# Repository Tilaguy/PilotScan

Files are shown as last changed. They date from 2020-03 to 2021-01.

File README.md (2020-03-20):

## PILOT SCAN
---
### 1. Descripción

En este repositorio se encuentran alojados los algoritmos necesarios para elaborar una interfaz de comunicación codificada con capacidad de detección de errores, durante el proceso de envío. Esta interfaz hace parte del sistema titulado **PilotScan\***, el cual consta de un sistema central de procesamiento y un sistema de respaldo que monitora de forma continua, el estado del sistema tanto a nivel hardware como software, además tiene la capacidad de realizar acciones indicadas por sistema central, sobre los diferentes módulos que conforman el sistema.

Para el sistema central de procesamiento, se usa una **Intel®️ NUC Board** con Linux 16.04 server. Para el sistema de respaldo se emplea un **dsPIC 30F4011**, el cual conecta diferentes sensores analógicos y digitales, tiene la capacidad de habilitar y deshabilitar fuentes reguladas de *12 V* y *24 V*, además de emitir mensajes al usuario a través de una bocina y leds RGB programables.

**\*** La información detallada del sistema se encuentra alojada en el repositorio: \ link \

---
## 2. Repository organization
Este repositorio se encuentra organizado de la siguiente forma:

### 2.1. PIC
* *Timer.c*:  Este archivo genera un reloj a frecuencia constante en un microcontrolador **PIC 16f506**, el cual sirve como base de tiempo para garantizar que el sistema de firmware está en funcionamiento.
### 2.2. Python
Estos archivos son nodos para ROS, los cuales interactúan entre sí por medio de tópicos para el monitoreo, procesamiento y acción sobre los diferentes módulos que conforman el sistema **PilotScan**.

* *Firmware.py*:  Nodo encargado de la recepción y transmisión serial con el sistema de respaldo.

* *Monitoring.py*:  Nodo encargado del procesamiento, codificación y decodificación de la información mediante protocolos diseñados para cada caso específico.

* *Resources.py*:  Nodo que lee la información del estado del sistema y la publica por medio de tópicos separados como el estado de memoria, la temperatura de los núcleos y entre otros.

### 2.3. dsPIC
#### 2.3.1. Include

* *ports.h*:  Librería para hacer asignaciones de pines según su uso y declaración de variables globales.

* *NOTAS.C*:  Librería para definir el tiempo de una nota usada por el Buzzer en el sistema.

* *TONOS.C*:  Librería donde se definen las notas musicales separado por octavas en 4 grupos de frecuencias diferentes.

* *SerialProtocol.h*:  Librería encargada de la codificación y decodificación de la información mediante protocolos diseñados para cada caso específico.

* *Hadware_actions.h*:  Librería usada para generar acciones o notificaciones del estado del sistema mediante el buzzer o los LEDs RGB.

* *Nuc_interface.h*:  Librería usada para encender y apagar el sistema de cómputo central.

* *I2C_DIR*:  Libreria que contiene las definiciones de direcciones I2C para la comunicación con algunos sensores, las funciones correspondientes para establecer dicha comunicación.

#### 2.3.2. Main
En el archivo main.c se hace uso de las librerías mencionadas anteriormente, se realiza la configuración de los diferentes periféricos de microcontrolador como modulo ADC, I2C, RS232, entre otros. Adicionalmente, se realiza la configuración y activación de interrupciones.

---

## 3. Protocolo de comunicación serial **computador-dsPIC**
El protocolo que se usa para la comunicación entre el microcontrolador y el computador genera un número que codifica la información en hexadecimal, esta codificación depende de quién es emisor del mensaje, esta codificación se explica más detalladamente a continuación. Además, el protocolo cuenta con un Byte de inicio (*'$'*) que indica el comienzo del mensaje y un salto de línea (*'\n'*) que informa el final. En cualquier caso, si los Bytes de información toman los valores de 0, significa un error en la codificación.

### 3.1. Protocolo de envió desde la Intel® NUC Board
Este protocolo se construye a partir de una tabla de valores constantes, los cuales indican el estado del sistema en diferentes ámbitos tales como: monitoreo y control de las fuentes, la comunicación de problemas de ejecución y otros requerimientos necesarios para el correcto funcionamiento del sistema. Dicho protocolo consta de dos Byte, los cuales codifican la información.

El primer Byte (**data1**) indica el origen de la información (VN-300, LiDAR, estado del sistema, etc.) de la cual se está dando a conocer su estado. El segundo Byte (**data2**) informa el estado y da idea de cómo debe proceder el microcontrolador. Los dos Bytes restantes corresponden al checksum, quien funciona como sistema de detección de errores en el proceso de comunicación, pues dichos Bytes deben corresponden a la suma de los dos primeros (**dato1+dato2**).

Cada mensaje es interpretado por el microcontrolador quien efectúa algún tipo de acción, ya sea realizando un encendido o apagado de algún elemento, activando alertas auditivas o alertas visuales a través de leds RGB.

* **P. ej.** Si la *temperatura media de los núcleos del sistema de cómputo* esta entre 35 °C y 40 °C, en microcontrolador debe *encender los ventiladores* en cierta forma particular.
  * Mensaje enviado:
  ~~~
  data1 =      0x4
  data2 =      0xE
  checksum =   0x12
  mensaje =    '$19986\n'
  ~~~
  * Acción tomada por el microcontrolador:
  ~~~
  - Encendido de ventilador ( PWM ~ 60% )
  - LED RGB 4 ([R,G,B] = [25,128,0])
  ~~~
#### Tabla 3.1.1. Mensajes del sistema.

data 1 | data 2 | message | meaning
-- | -- | -- | -- 
0 | 0 |         |Reserve
0 | 1 | sys-on_24 |	Turn-on source 24V
0 | 2 | sys-off_12 |Turn-off source 12V
0 | 3 | sys-off_24 |Turn-off source 24V
0 | 4 | sys-mem_E |	Memory problem
0 | 5 | sys-on_m8 |	Turn LiDAR on
0 | 6 | sys-on_tty |Turn all tty ports on
0 | 7 |
0 | 8 |
0 | 9 |
0 | A |
0 | B |
0 | C |
0 | D |
0 | E |
0 | F |

#### Tabla 3.1.2. Mensajes del estado del VN300.
data 1 | data 2 | message | meaning | R | G | B |LED
-- | -- | -- | -- | -- | -- | -- |--
1 | 0 |         |Reserve|0|0|0|L1
1 | 1 | VN300-NC |	VN300 No Connected|240|0|0|L1
1 | 2 | VN300-Start |VN 300 Starting|240|128|0|L1
1 | 3 | VN300-<25 | VN300 <25%|50|0|240|L1
1 | 4 | VN300-<50 |25% < VN300 <50%|50|80|160|L1
1 | 5 | VN300-<75 |	50% < VN300 <75|50|160|80|L1
1 | 6 | VN300->75 |VN300 >75%|50|240|0|L1
1 | 7 |VN300-Work | VN300 Working|0|240|0|L1
1 | 8 |
1 | 9 |
1 | A |
1 | B |
1 | C |
1 | D |
1 | E |
1 | F |

#### Tabla 3.1.3. Mensajes del estado del LiDAR M8.
data 1 | data 2 | message | meaning | R | G | B |LED
-- | -- | -- | -- | -- | -- | -- | --
2 | 0 |         |Reserve|0|0|0|L2
2 | 1 | M8-NC |	M8 No Ping|240	|0|0|L2
2 | 2 | M8-Start |M8 Starting|240|128|0|L2
2 | 3 |
2 | 4 |
2 | 5 |
2 | 6 |
2 | 7 |M8-Work | M8 Working|0|240|0 |L2
2 | 8 |
2 | 9 |
2 | A |
2 | B |
2 | C |
2 | D |
2 | E |
2 | F |
#### Tabla 3.1.4. Mensajes del estado de la cámara.
data 1 | data 2 | message | meaning
-- | -- | -- | --
3 | 0 |         |Reserve
3 | 1 | CAM-NC | CAM No Connected
3 | 2 | CAM-Start |CAM Starting
3 | 3 |  |
3 | 4 |  |
3 | 5 |  |
3 | 6 |  |
3 | 7 |CAM-Work | CAM Working
3 | 8 |
3 | 9 |
3 | A |
3 | B |
3 | C |
3 | D |
3 | E |
3 | F |
#### Tabla 3.1.5. Mensajes del control Fuzzy para temperatura.
data 1 | data 2 | message | meaning | R | G | B|LED
-- | -- | -- | -- | -- | -- | -- |--
3 | 0 |  |Reserve|0|0|0|L4
3 | 1 |   
3 | 2 |  
3 | 3 |  
3 | 4 |  
3 | 5 |  
3 | 6 |  
3 | 7 |   
3 | 8 |
3 | 9 |
3 | A |
3 | B |
3 | C |FUZZ-T1|>25°|13	|0|	125|L4
3 | D |FUZZ-T2|>30°|113|	0|	125|L4
3 | E |FUZZ-T3|>35°|255|	128|	0|L4
3 | F |FUZZ-T4|>40°|250|0|	0|L4
#### Tabla 3.1.6. Mensajes de error de memoria.
data 1 | data 2 | message | meaning | R | G | B |LED
-- | -- | -- | -- | -- | -- | -- | --
A | 0 |  |Reserve|0|0|0|L3
A | 1 | memo-RAM_E1 |RAM alert1|255|64|64|L3
A | 2 | memo-RAM_E2 |RAM alert2|255|0|0|L3
A | 3 |
A | 4 |
A | 5 |
A | 6 | memo-ROM_E1 |ROM alert1|64|133|255 |L3
A | 7 | memo-ROM_E2 |ROM alert2|64|64|255|L3
A | 8 | memo-ROM_E3 |ROM alert3|0|0|255|L3
A | 9 |
A | A |
A | B |
A | C |
A | D |
A | E |
A | F |
### 3.2. Protocolo de envío desde el dsPIC
Este protocolo se construye a partir de una tabla de valores constantes y los datos numéricos codificados en hexadecimal, que informan al computador sobre las variables medidas por el microcontrolador. Dicho protocolo consta de tres Bytes que codifican la información, los cuales son enviados al computador para ponerlo en conocimiento de los valores numéricos de las variables fundamentales para el funcionamiento de las tarjetas.

El primer Byte corresponde al tipo de información (**command**) como corrientes, voltajes, etc., y su origen. Los siguientes dos Bytes son la información numérica codificada (**data1**, **data2**), la cual puede ser entera o flotante. Adicionalmente, existen dos Bytes corresponden al checksum, el cual permite verificar la información transmitida como protocolo de detección de errores y además permite conocer si el dato numérico enviado es un entero con rango [0, 255] (**command+data1+data2+0x05**), o un flotante con una cifra decimal de precisión (**command+data1+data2**).

* **P. ej.** La *corriente proveniente de la fuente de 5 V* medida por el sensor es de *0.45 A*, a su vez *el altímetro* detecta una altura de *64 m*.
  * Mensaje 1 enviado:
  ~~~
  Command =    0x1
  data1 =      0x0
  data2 =      0x4
  checksum =   0x05
  mensaje =    '$66565\n'
  ~~~
  * Mensaje 2 enviado:
  ~~~
  Command =    0xD
  data1 =      0x4
  data2 =      0x0
  checksum =   0x16
  mensaje =    '$868374\n'
  ~~~
#### Tabla 3.2.1. Variables medidas codificadas.
   
Command|	data1|	data2|	meaning|
|--|--|--|--|
0|	|	|	Reserved|
1|	x|	y|	current source 5 "x.y"|
2|	x|	y|	current source 12 "x.y"|
3|	x|	y|	current source 24 "x.y"|
4|	x|	y|	current source battery "x.y"|
5|	x|	y|	Voltage source 5 "x.y"|
6|	x|	y|	Voltage source 12 "x.y"|
7|	x|	y|	Voltage source 24 "x.y"|
8|	x|	y|	Voltage source Battery "x.y"|
9|	x|	y|	Temperature LiDAR|
A|	x|	y|	Temperature dsPIC|
B|	x|	y|	Temperature DC|
C|	x|	y|	Temperature xx|
D|	x|	y|	Hight|

#### Tabla 3.2.2. Estado de los módulos del sistema.
|Command|	data1|	data2|	meaning|
|--|--|--|--|
|F	|0	|0	|Reserved|
|F	|0	|1	|12 V is on|
|F	|1	|0	|24 V is on|
|F	|1	|1	|All sources are on|
|F	|0	|2	|12 V is going to shut it down in 1 m|
|F	|2	|0	|24 V is going to shut it down in 1 m|
|F	|2	|2	|All sources are going to shut it down in 1 m|
|F	|0	|3	|shut LiDAR down |
|F	|3	|0	|close all tty ports|
|F	|3	|3	|shut ROS down |
|F	|0	|4	|turn LiDAR on|
|F	|4	|0	|turn all tty ports on|
|F	|4	|4	|turn ROS on|

---

### 4. Software requirements for computer

#### 4.1. ROS Kinetic instaliation

To install robot operating system (ROS) in the kinetic version for ubuntu 16.04, you should follow the steeps descrived in http://wiki.ros.org/kinetic/Installation/Ubuntu.

#### 4.2. VN300 ROS node

The installing of VN-300 node for ROS, it begins with downloading the repository in *workspace/src* directory.
~~~
$ git clone https://github.com/HaroldMurcia/vectornav.git
~~~
Afeter that, you have to compilate the *workspace* directory.
~~~
$ catkin_make
$ source devel/setup.bash
~~~
Finaly, The node could be launched with ROS instrction:
~~~
$ roslaunch vectornav vectornav.launch
~~~
#### 4.3. Quanergy M8 liDAR

To be able to launch the ROS node of Quanergy M8 LiDAR, you have to follow the steeps of the next repository.
https://github.com/mfassler/python3-quanergyM8

#### 4.1. System_monitor Installation
La instalación del System_monitor node para ROS: (https://github.com/RobotnikAutomation/system_monitor)

Dentro de la carpeta *src* del *workspace*, se debe descargar el *system_monitor* usando la siguiente instrucción:
~~~
$ git clone https://github.com/RobotnikAutomation/system_monitor
~~~
Es necesario instalar algunas dependencias adicionales para su ejecución,
~~~
$ sudo apt-get install sysstat ifstat ntpdate
~~~
Luego, se compila en el *workspace* y se asigna el directorio *devel*,
~~~
$ catkin_make
$ source devel/setup.bash
~~~
Por último, para lanzar el nodo se usa la instrucción:
~~~
$ roslaunch system_monitor system_monitor.launch
~~~

---
### 5. Authors.

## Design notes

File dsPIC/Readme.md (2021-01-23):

https://microchipdeveloper.com/xc16:installation
http://ww1.microchip.com/downloads/en/DeviceDoc/MPLAB%20XC16%20C%20Compiler%20Users%20Guide%20DS50002071H.pdf

https://docs.google.com/spreadsheets/d/1N3Q6yQt_chxxuJ2aqFqy1saBSvcKVxSeXHLgSlUjSdI/edit#gid=646067530

https://mail.google.com/mail/u/0/#inbox/FMfcgxwJXfprBbCdzCzRqRrNFmxLfNfq

chmod -R 777 MPLAB....

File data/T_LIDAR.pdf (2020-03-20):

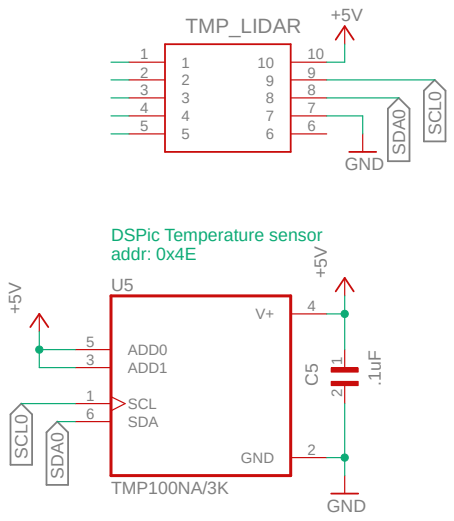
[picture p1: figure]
GND; TMP100NA/3K; GND ⁺⁵V; 10 10 TMP_LIDAR; ADD1 3; ADD0 5; SCL 1; 2 SDA 6; 1 2 C5 SCL0 SCL0 SDA0 SDA0; DSPic Temperature sensor addr: 0x4E

20/03/2020 17:03 C:\Users\Sebastian_Tilaguy\Documents\EAGLE\projects\PilotScan\T_LIDAR.sch (Sheet: 1/1)

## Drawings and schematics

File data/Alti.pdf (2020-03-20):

# MCLK MCLK SDA²

# SDA2 SCL2

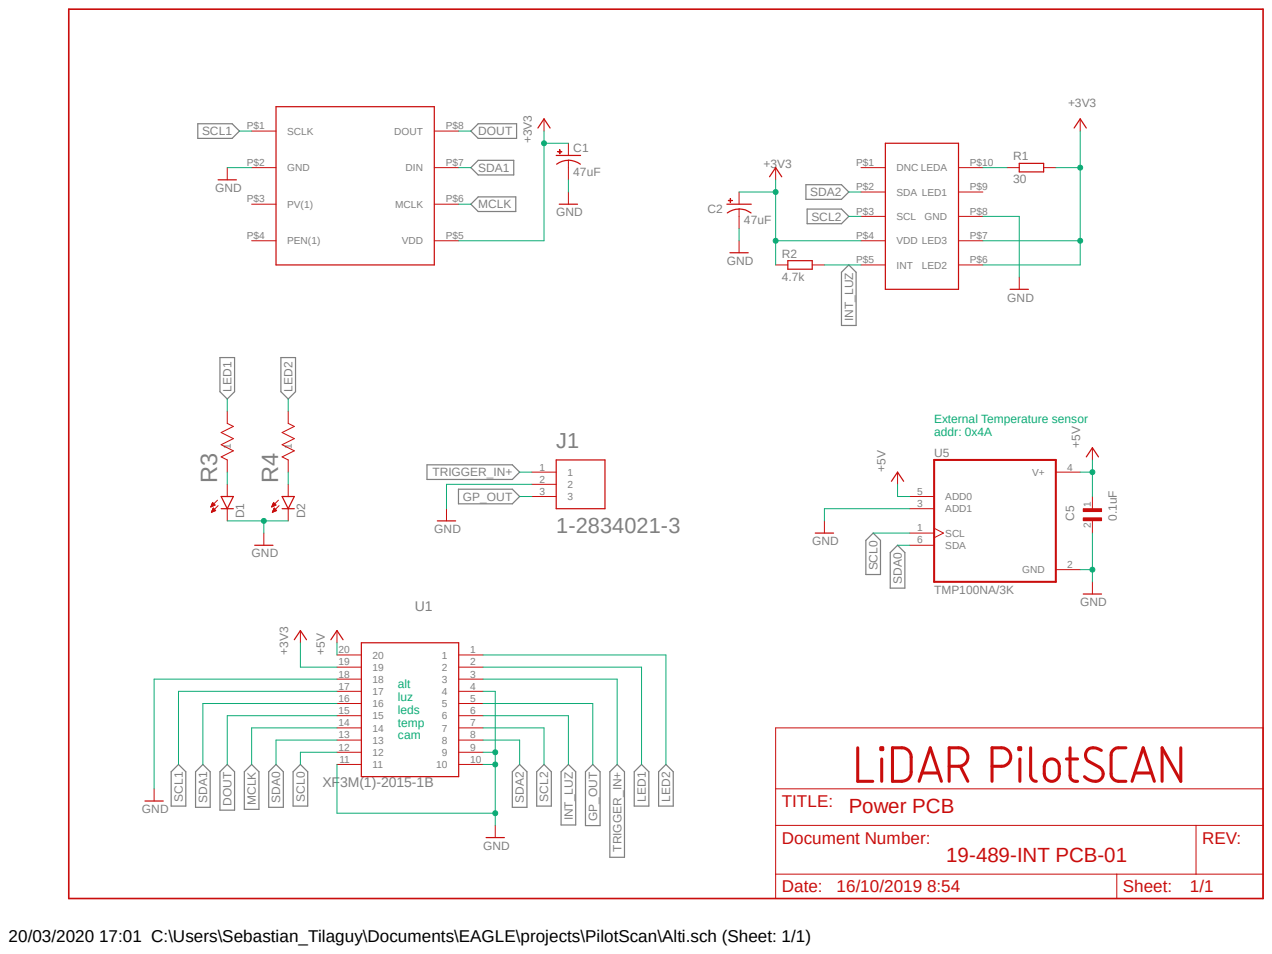
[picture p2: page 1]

TRIGGER_IN+ | 1 2 3

Document Number: 19-489-INT PCB-01 | REV:

Date: 16/10/2019 8:54 | Sheet: 1/1

20/03/2020 17:01 C:\Users\Sebastian_Tilaguy\Documents\EAGLE\projects\PilotScan\Alti.sch (Sheet: 1/1)

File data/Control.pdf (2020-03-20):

# Prog

# XF3M(1)-2015-1B ⁺³V³ +5V

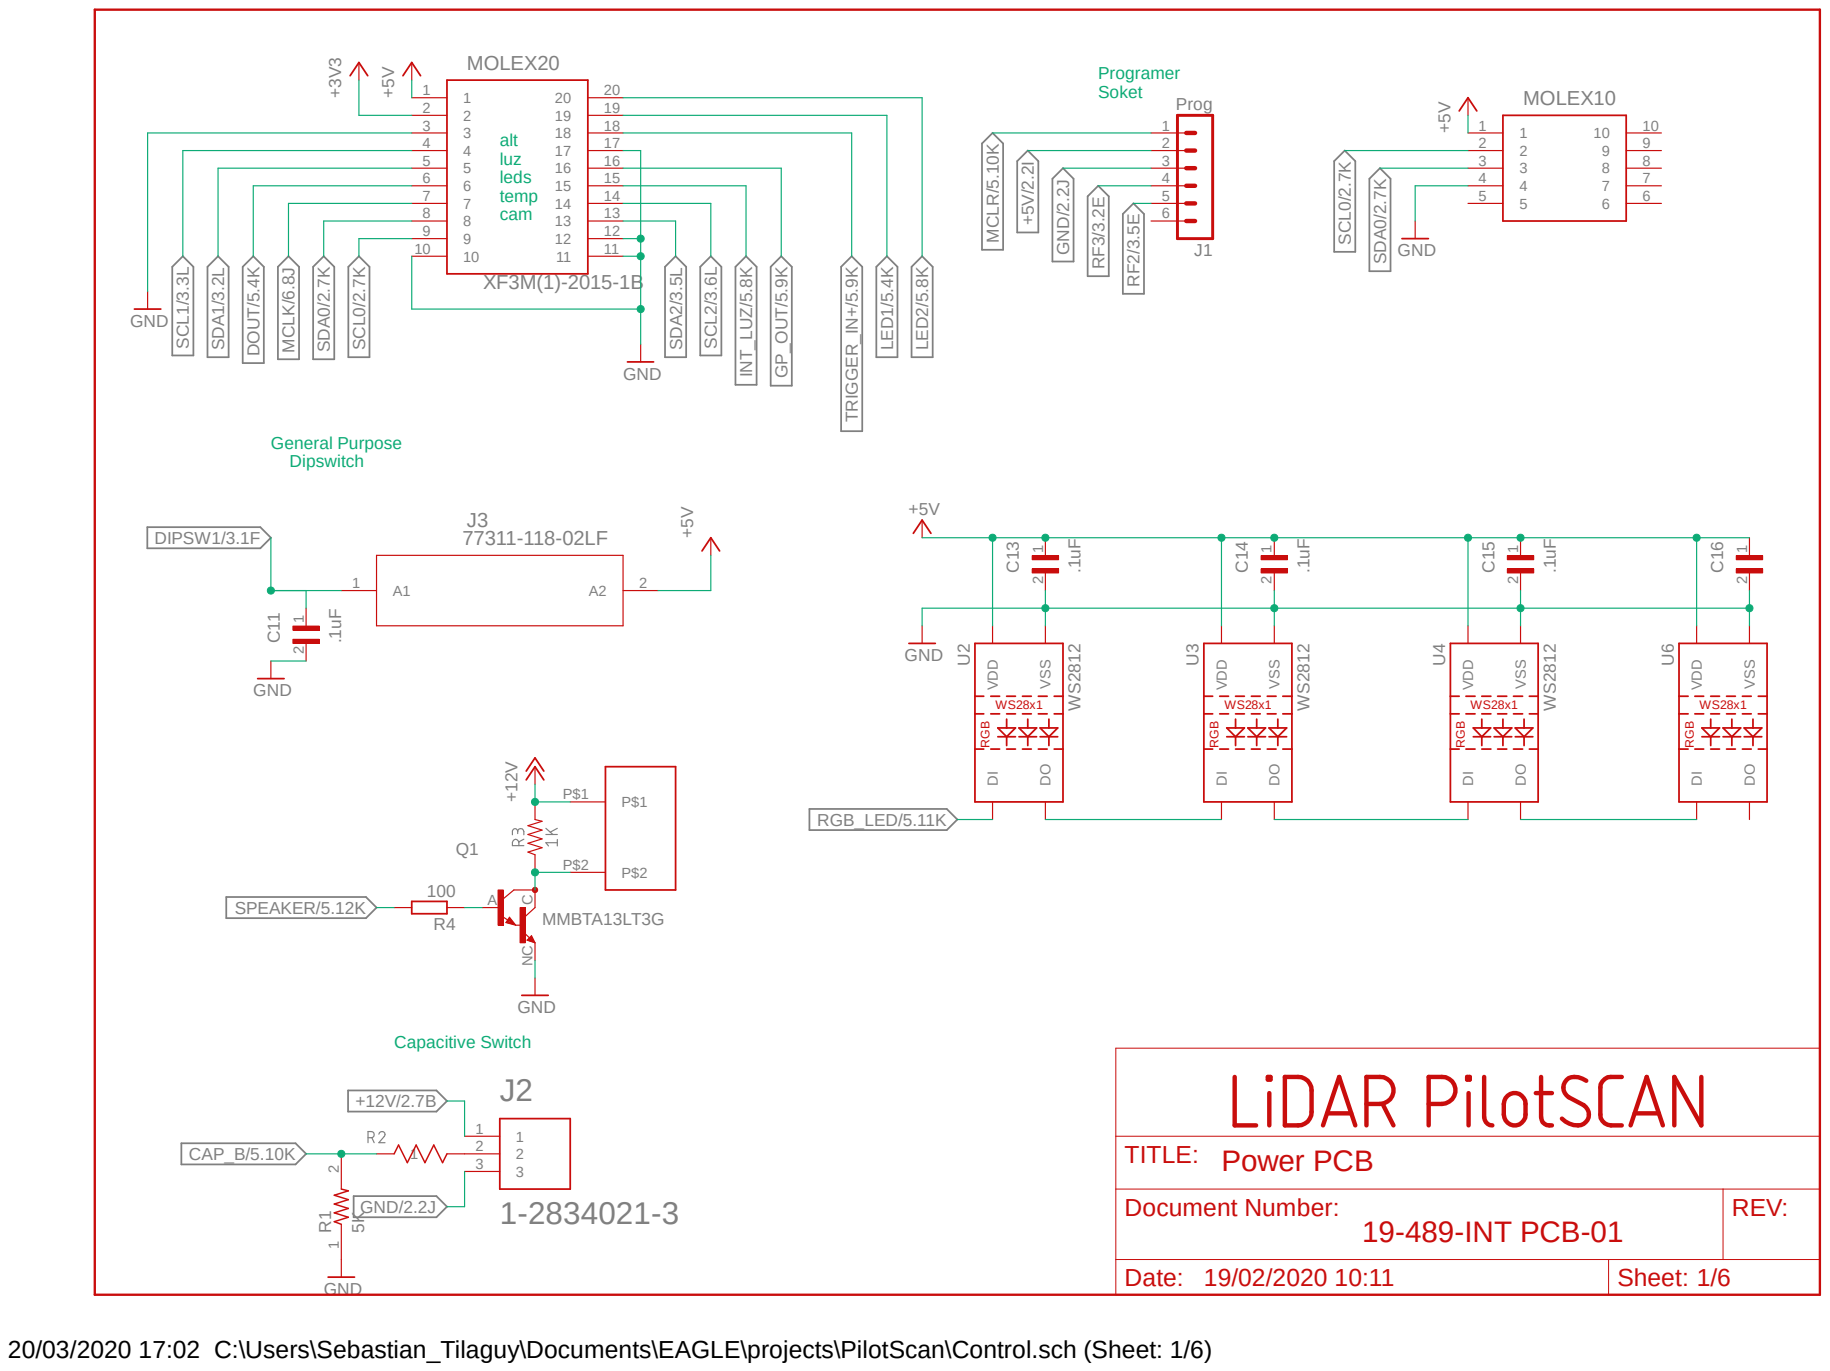
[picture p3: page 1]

20/03/2020 17:02 C:\Users\Sebastian_Tilaguy\Documents\EAGLE\projects\PilotScan\Control.sch (Sheet: 1/6) ⁺¹²V

Document Number: 19-489-INT PCB-01 | REV:

Date: | Sheet:

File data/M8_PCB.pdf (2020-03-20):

# 8 Q-M8

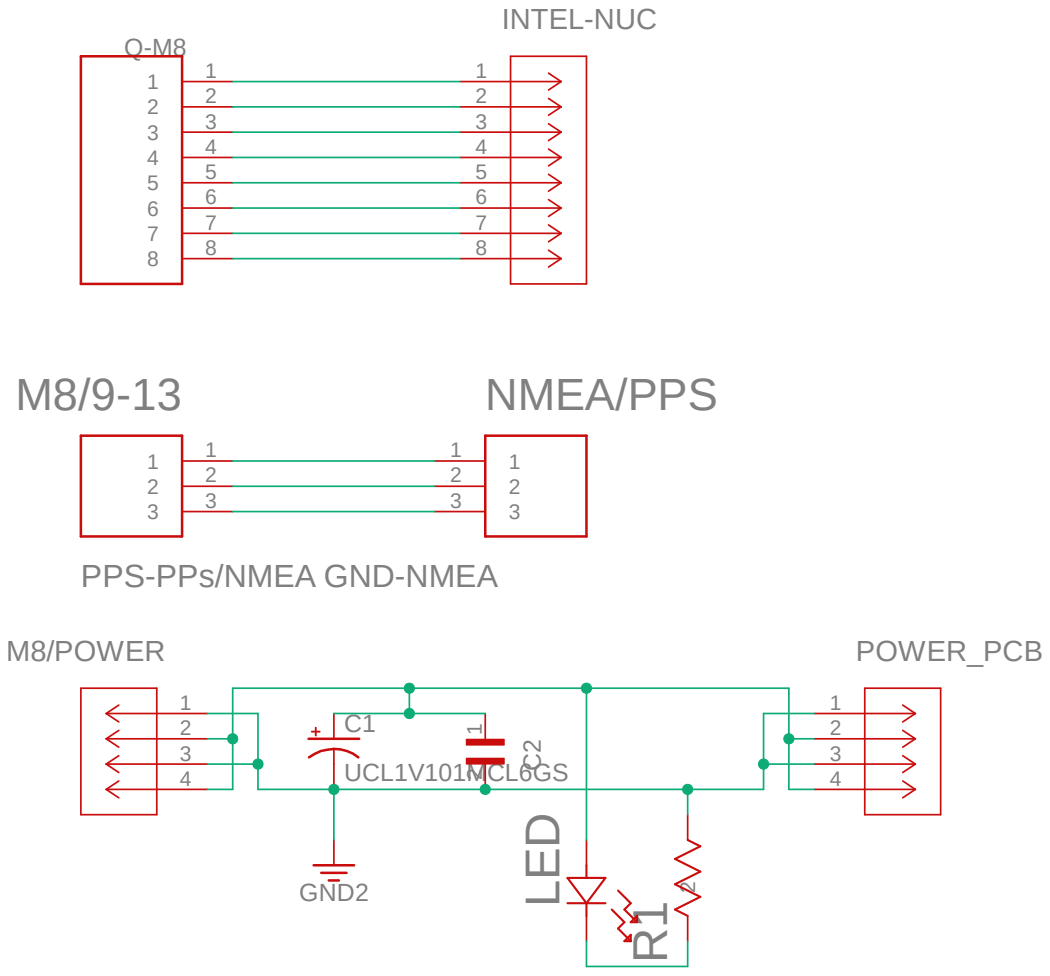
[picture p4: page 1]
PPS-PPs/NMEA GND-NMEA; UCL1V101MCL6GS; GND2; INTEL-NUC; 3 NMEA/PPS; 4 M8/POWER; 4 POWER_PCB; C² LED; TITLE:; Q-M8 PCB

Document Number: 19-489-INT PCB-03 | REV:

Date: 16/10/2019 8:54 | Sheet: 1/1

20/03/2020 17:02 C:\Users\Sebastian_Tilaguy\Documents\EAGLE\projects\PilotScan\M8_PCB.sch (Sheet: 1/1)

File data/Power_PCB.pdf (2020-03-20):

XT60 | NTCS⁰⁴⁰²E³¹⁰³JLT | NTCS⁰⁴⁰²E³¹⁰³JLT | GCM¹⁸⁸R⁷¹C⁴⁷⁴KA⁵⁵D | CZRU⁵²C⁴V⁷ | CZRU⁵²C⁴V⁷

# RNCP1206FTD150R

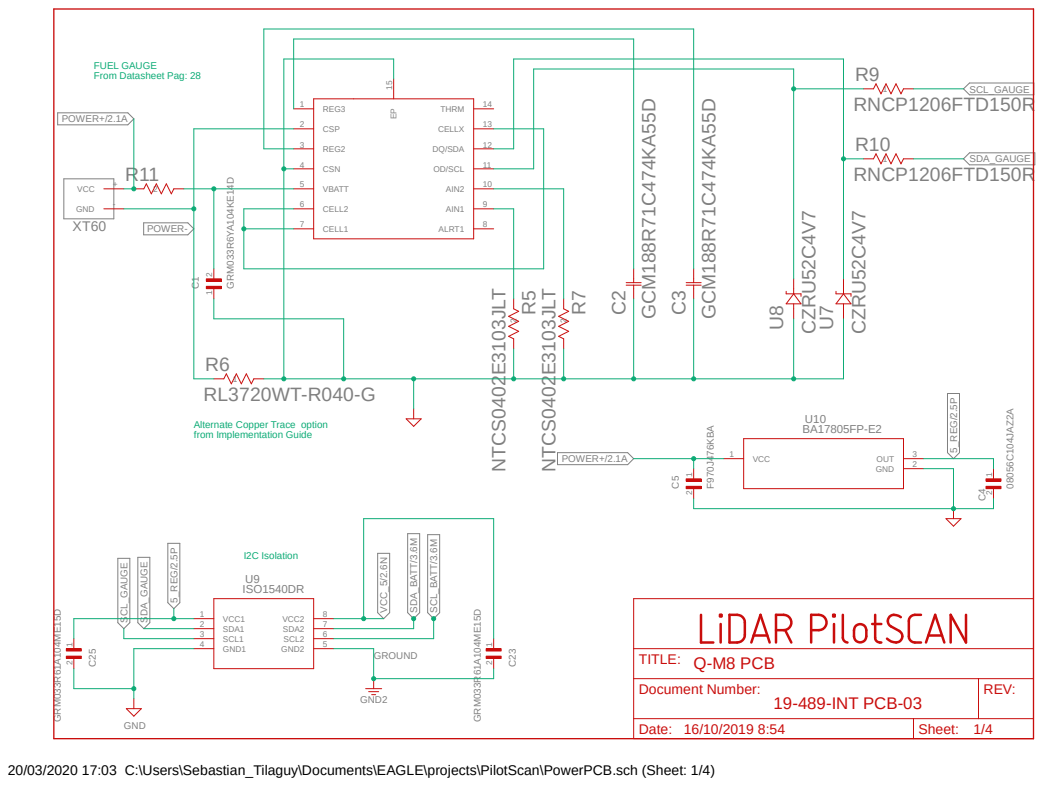
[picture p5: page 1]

Alternate Copper Trace option
from Implementation Guide

Document Number: 19-489-INT PCB-03 | REV:

Date: 16/10/2019 8:54 | Sheet: 1/4

20/03/2020 17:03 C:\Users\Sebastian_Tilaguy\Documents\EAGLE\projects\PilotScan\PowerPCB.sch (Sheet: 1/4)

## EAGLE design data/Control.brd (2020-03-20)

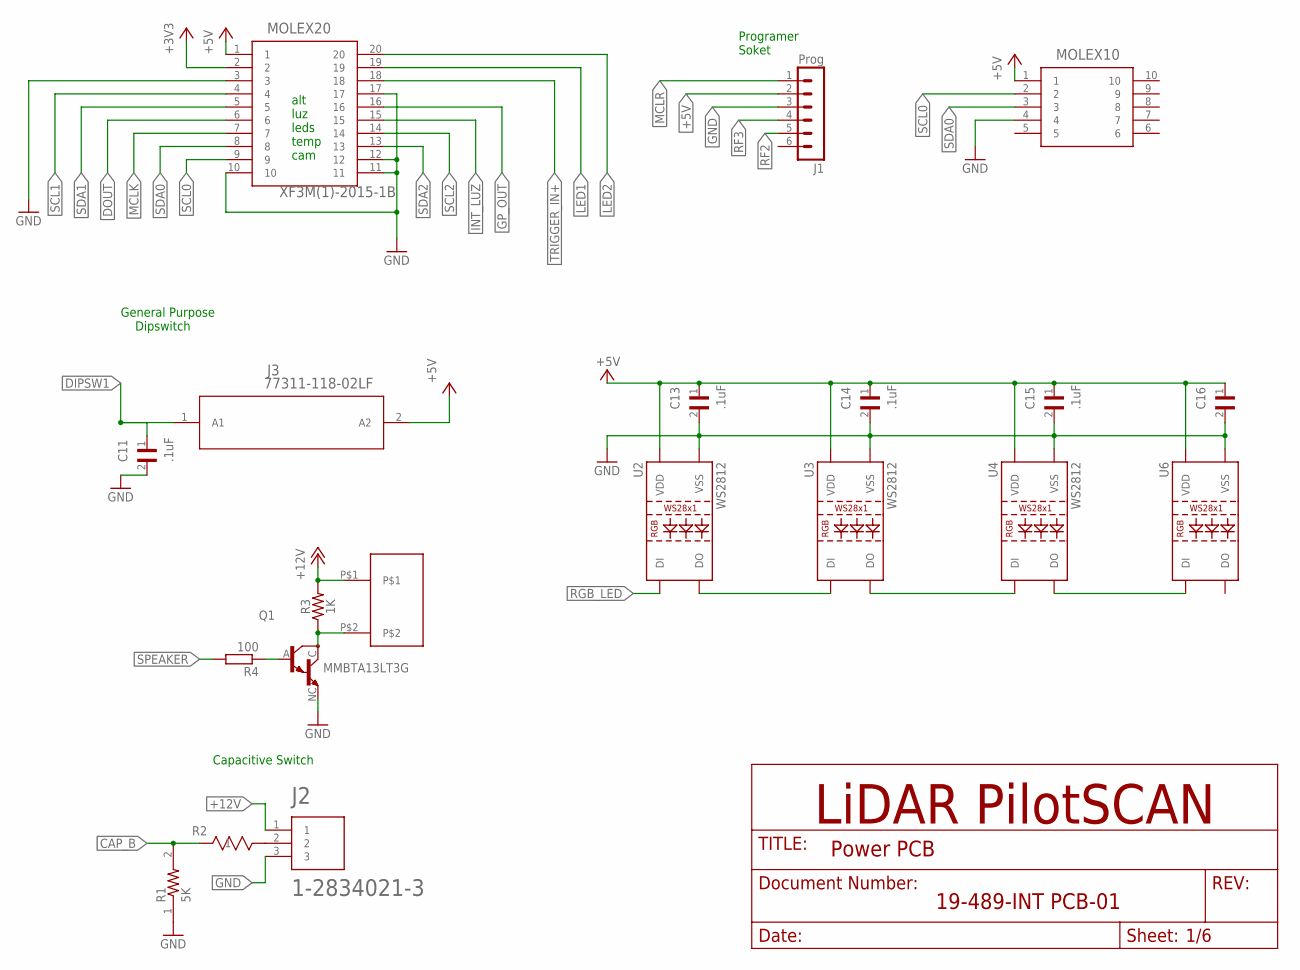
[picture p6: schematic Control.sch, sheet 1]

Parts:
BUZZ1: PS1240P02BT
C11, C13, C14, C15, C16: .1uF; CAPC2012X140N
J1: Prog; MA06-1
J2: 1-2834021-3; CONN_1-2834021-3
J3: 77311-118-02LF
MOLEX10: 522071060
MOLEX20: XF3M(1)-2015-1B
Q1: MMBTA13LT3G
R1: 5K; RESC2012X60
R2: 6K8; RES_RC0201_P6XP3
R3: 1K; AXIAL-0.3
R4: 100; RMCF0805JT270R
U2, U3, U4, U6: WS2812; LED-TRICOLOR-5050-IC

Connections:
+3V3: MOLEX20.2; also elsewhere on the board
+5V: C13.1, C14.1, C15.1, C16.1, J1.2, J3.2 (A2), MOLEX10.1, MOLEX20.1, U2.3 (VDD), U2.5 (VDD), U3.3 (VDD), U3.5 (VDD), U4.3 (VDD), U4.5 (VDD), U6.3 (VDD), U6.5 (VDD); also elsewhere on the board
+12V: BUZZ1.P$1, J2.1, R3.P$2 (2); also elsewhere on the board
CAP_B: R1.2, R2.1; also elsewhere on the board
DIPSW1: C11.1, J3.1 (A1); also elsewhere on the board
DOUT: MOLEX20.6; also elsewhere on the board
GND: C11.2, C13.2, C14.2, C15.2, C16.2, J1.3, J2.3, MOLEX10.4, MOLEX20.3, MOLEX20.10, MOLEX20.11, MOLEX20.12, MOLEX20.17, Q1.NC (E), R1.1, U2.6 (VSS), U3.6 (VSS), U4.6 (VSS), U6.6 (VSS); also elsewhere on the board
GP_OUT: MOLEX20.16; also elsewhere on the board
INT_LUZ: MOLEX20.15; also elsewhere on the board
LED1: MOLEX20.19; also elsewhere on the board
LED2: MOLEX20.20; also elsewhere on the board
MCLK: MOLEX20.7; also elsewhere on the board
MCLR: J1.1; also elsewhere on the board
unnamed: Q1.A (B), R4.1
unnamed: BUZZ1.P$2, Q1.C, R3.P$1 (1)
unnamed: J2.2, R2.2
unnamed: U2.1 (DO), U3.2 (DI)
unnamed: U3.1 (DO), U4.2 (DI)
unnamed: U4.1 (DO), U6.2 (DI)
RF2: J1.5; also elsewhere on the board
RF3: J1.4; also elsewhere on the board
RGB_LED: U2.2 (DI); also elsewhere on the board
SCL0: MOLEX10.2, MOLEX20.9; also elsewhere on the board
SCL1: MOLEX20.4; also elsewhere on the board
SCL2: MOLEX20.14; also elsewhere on the board
SDA0: MOLEX10.3, MOLEX20.8; also elsewhere on the board
SDA1: MOLEX20.5; also elsewhere on the board
SDA2: MOLEX20.13; also elsewhere on the board
SPEAKER: R4.2; also elsewhere on the board
TRIGGER_IN+: MOLEX20.18; also elsewhere on the board

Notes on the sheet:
Programer Soket
General Purpose Dipswitch
Capacitive Switch
alt luz leds temp cam

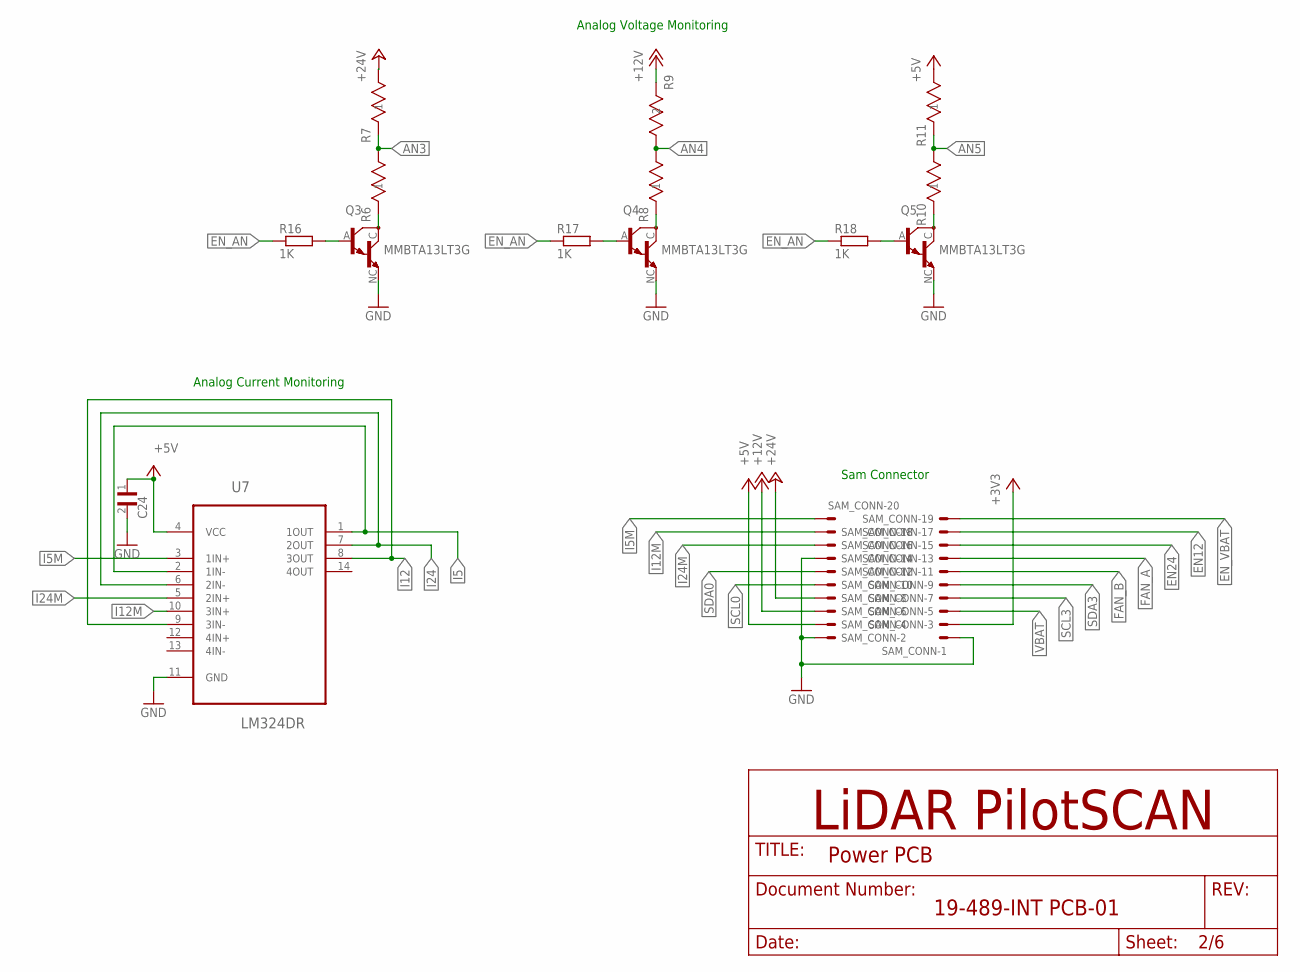
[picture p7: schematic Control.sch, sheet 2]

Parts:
C24: 08056C104JAZ2A; CAPC2012X140N
Q3, Q4, Q5: MMBTA13LT3G
R6, R8, R10: 1K8; RES_RC0201_P6XP3
R7: 18K; RES_RC0201_P6XP3
R9: 8K2; RES0805_CRG_TYCO-L
R11: 1K5; YAG_R0201
R16, R17, R18: 1K; RMCF0805FT1K00
SAM_CONN: IPT1-110-01-L-D
U7: LM324DR; SOIC127P600X175-14N

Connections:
+3V3: SAM_CONN.P$3; also elsewhere on the board
+5V: C24.1, R11.2, SAM_CONN.P$4, U7.4 (VCC); also elsewhere on the board
+12V: R9.2, SAM_CONN.P$6; also elsewhere on the board
+24V: R7.2, SAM_CONN.P$8
AN3: R6.2, R7.1; also elsewhere on the board
AN4: R8.2, R9.1; also elsewhere on the board
AN5: R10.2, R11.1; also elsewhere on the board
EN12: SAM_CONN.P$17; also elsewhere on the board
EN_AN: R16.1, R17.1, R18.1; also elsewhere on the board
EN_VBAT: SAM_CONN.P$19; also elsewhere on the board
ESRDTFYGHUJI: Q4.C, R8.1
FAN_A: SAM_CONN.P$13; also elsewhere on the board
FAN_B: SAM_CONN.P$11; also elsewhere on the board
GND: C24.2, Q3.NC (E), Q4.NC (E), Q5.NC (E), SAM_CONN.P$1, SAM_CONN.P$2, SAM_CONN.P$14, U7.11 (GND); also elsewhere on the board
I5: U7.1 (1OUT), U7.2 (1IN-); also elsewhere on the board
I5M: SAM_CONN.P$20, U7.3 (1IN+)
I12: U7.8 (3OUT), U7.9 (3IN-); also elsewhere on the board
I12M: SAM_CONN.P$18, U7.10 (3IN+)
I24: U7.6 (2IN-), U7.7 (2OUT); also elsewhere on the board
I24M: SAM_CONN.P$16, U7.5 (2IN+)
unnamed: Q3.A (B), R16.2
unnamed: Q3.C, R6.1
unnamed: Q4.A (B), R17.2
unnamed: Q5.C, R10.1
unnamed: Q5.A (B), R18.2
SCL0: SAM_CONN.P$10; also elsewhere on the board
SCL3: SAM_CONN.P$7; also elsewhere on the board
SDA0: SAM_CONN.P$12; also elsewhere on the board
SDA3: SAM_CONN.P$9; also elsewhere on the board
VBAT: SAM_CONN.P$5; also elsewhere on the board

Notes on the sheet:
Analog Voltage Monitoring
Analog Current Monitoring
Sam Connector

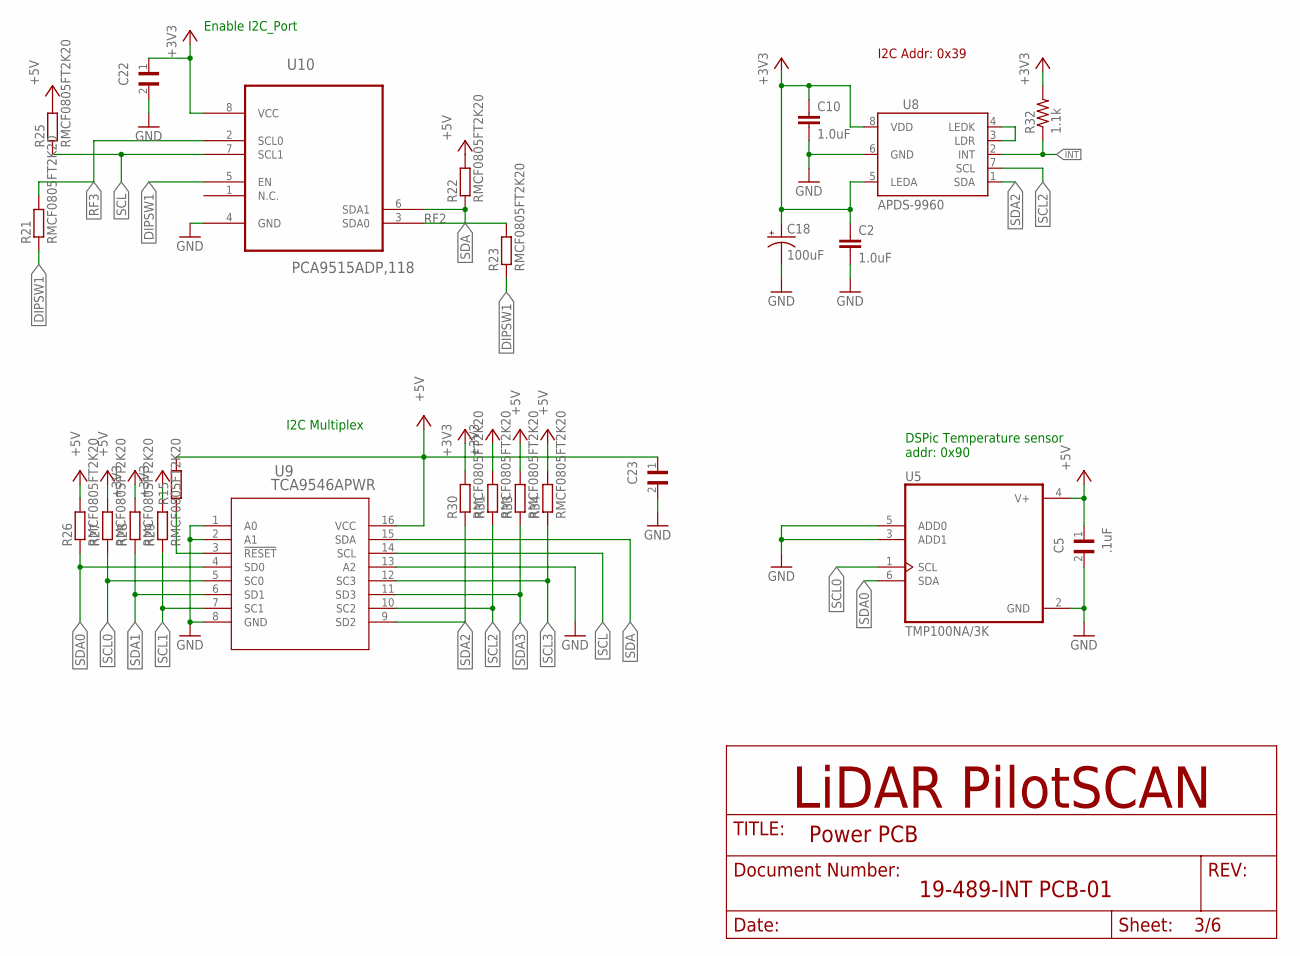
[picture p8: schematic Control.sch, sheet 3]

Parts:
C2, C10: 1.0uF; 0603-CAP
C5: .1uF; CAPC2012X140N
C18: 100uF; EIA7343
C22, C23: 08056C104JAZ2A; CAPC2012X140N
R15, R21, R22, R23, R25, R26, R27, R28, R29, R30, R31, R33, R34: RMCF0805FT2K20
R32: 1.1k; 0603-RES
U5: TMP100NA/3K
U8: APDS-9960
U9: TCA9546APWR; PW16
U10: PCA9515ADP,118; SOP65P490X110-8N

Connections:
+3V3: C2.1, C10.1, C18.A (+), C22.1, R28.2, R29.2, R30.2, R31.2, R32.2, U8.5 (LEDA), U8.8 (VDD), U10.8 (VCC); also elsewhere on the board
+5V: C5.1, C23.1, R15.2, R22.2, R25.2, R26.2, R27.2, R33.2, R34.2, U5.4 (V+), U9.16 (VCC); also elsewhere on the board
DIPSW1: R21.1, R23.1, U10.5 (EN); also elsewhere on the board
GND: C2.2, C5.2, C10.2, C18.C (-), C22.2, C23.2, U5.2 (GND), U5.3 (ADD1), U5.5 (ADD0), U8.6 (GND), U9.1 (A0), U9.2 (A1), U9.8 (GND), U9.13 (A2), U10.4 (GND); also elsewhere on the board
INT: R32.1, U8.2 (INT)
unnamed: U8.3 (LDR), U8.4 (LEDK)
unnamed: R15.1, U9.3 (!RESET)
RF2: R23.2, U10.3 (SDA0); also elsewhere on the board
RF3: R21.2, U10.2 (SCL0); also elsewhere on the board
SCL: R25.1, U9.14 (SCL), U10.7 (SCL1)
SCL0: R27.1, U5.1 (SCL), U9.5 (SC0); also elsewhere on the board
SCL1: R29.1, U9.7 (SC1); also elsewhere on the board
SCL2: R31.1, U8.7 (SCL), U9.10 (SC2); also elsewhere on the board
SCL3: R34.1, U9.12 (SC3); also elsewhere on the board
SDA: R22.1, U9.15 (SDA), U10.6 (SDA1)
SDA0: R26.1, U5.6 (SDA), U9.4 (SD0); also elsewhere on the board
SDA1: R28.1, U9.6 (SD1); also elsewhere on the board
SDA2: R30.1, U8.1 (SDA), U9.9 (SD2); also elsewhere on the board
SDA3: R33.1, U9.11 (SD3); also elsewhere on the board

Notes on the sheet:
Enable I2C_Port
I2C Addr: 0x39
I2C Multiplex
DSPic Temperature sensor addr: 0x90

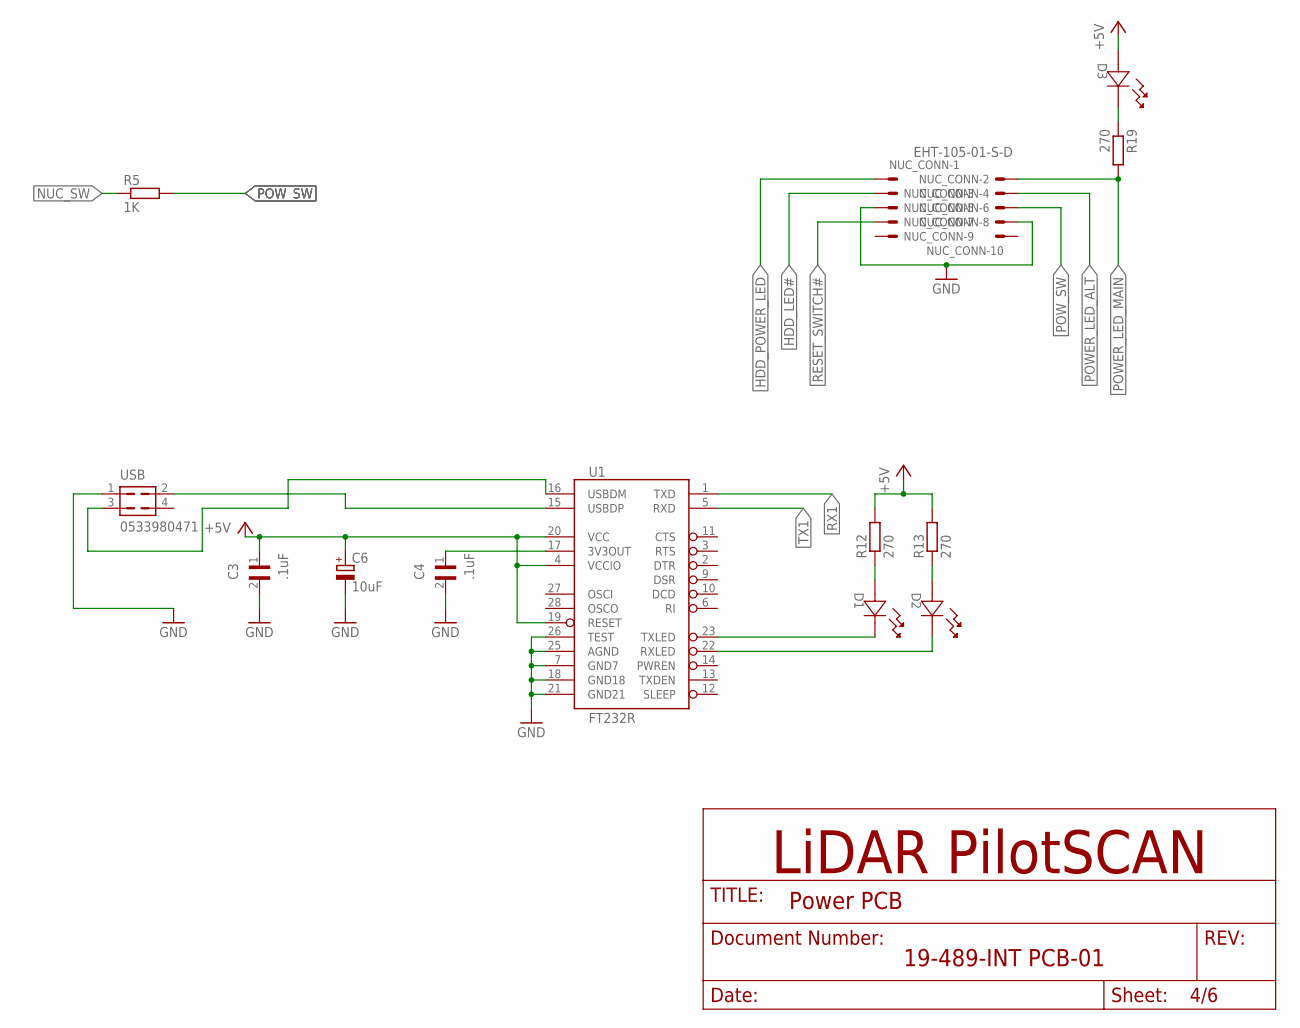
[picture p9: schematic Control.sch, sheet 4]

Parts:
C3, C4: .1uF; CAPC2012X140N
C6: 10uF; E1,8-4
D1, D2, D3: TLMS1100-GS08; LED_VISHAY_TLMX1100
NUC_CONN: EHT-105-01-S-D; 332-10
R5: 1K; RMCF0805FT1K00
R12, R13, R19: 270; RMCF0805JT270R
U1: FT232R; SSOP28DB
USB: 0533980471

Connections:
+5V: C3.1, C6.+, D3.2, R12.2, R13.2, U1.4 (VCCIO), U1.19 (RESET), U1.20 (VCC); also elsewhere on the board
GND: C3.2, C4.2, C6.-, NUC_CONN.5, NUC_CONN.8, U1.7 (GND7), U1.18 (GND18), U1.21 (GND21), U1.25 (AGND), U1.26 (TEST), USB.1; also elsewhere on the board
HDD_LED#: NUC_CONN.3
HDD_POWER_LED: NUC_CONN.1
unnamed: D1.2, R12.1
unnamed: C4.1, U1.17 (3V3OUT)
unnamed: D2.2, R13.1
unnamed: D3.1, R19.1
unnamed: U1.15 (USBDP), USB.2
unnamed: U1.16 (USBDM), USB.3
NUC_SW: R5.1; also elsewhere on the board
POWER_LED_ALT: NUC_CONN.4
POWER_LED_MAIN: NUC_CONN.2, R19.2; also elsewhere on the board
POW_SW: NUC_CONN.6, R5.2
RESET_SWITCH#: NUC_CONN.7
RX1: U1.1 (TXD); also elsewhere on the board
RXLED: D2.1, U1.22 (RXLED)
TX1: U1.5 (RXD); also elsewhere on the board
TXLED: D1.1, U1.23 (TXLED)

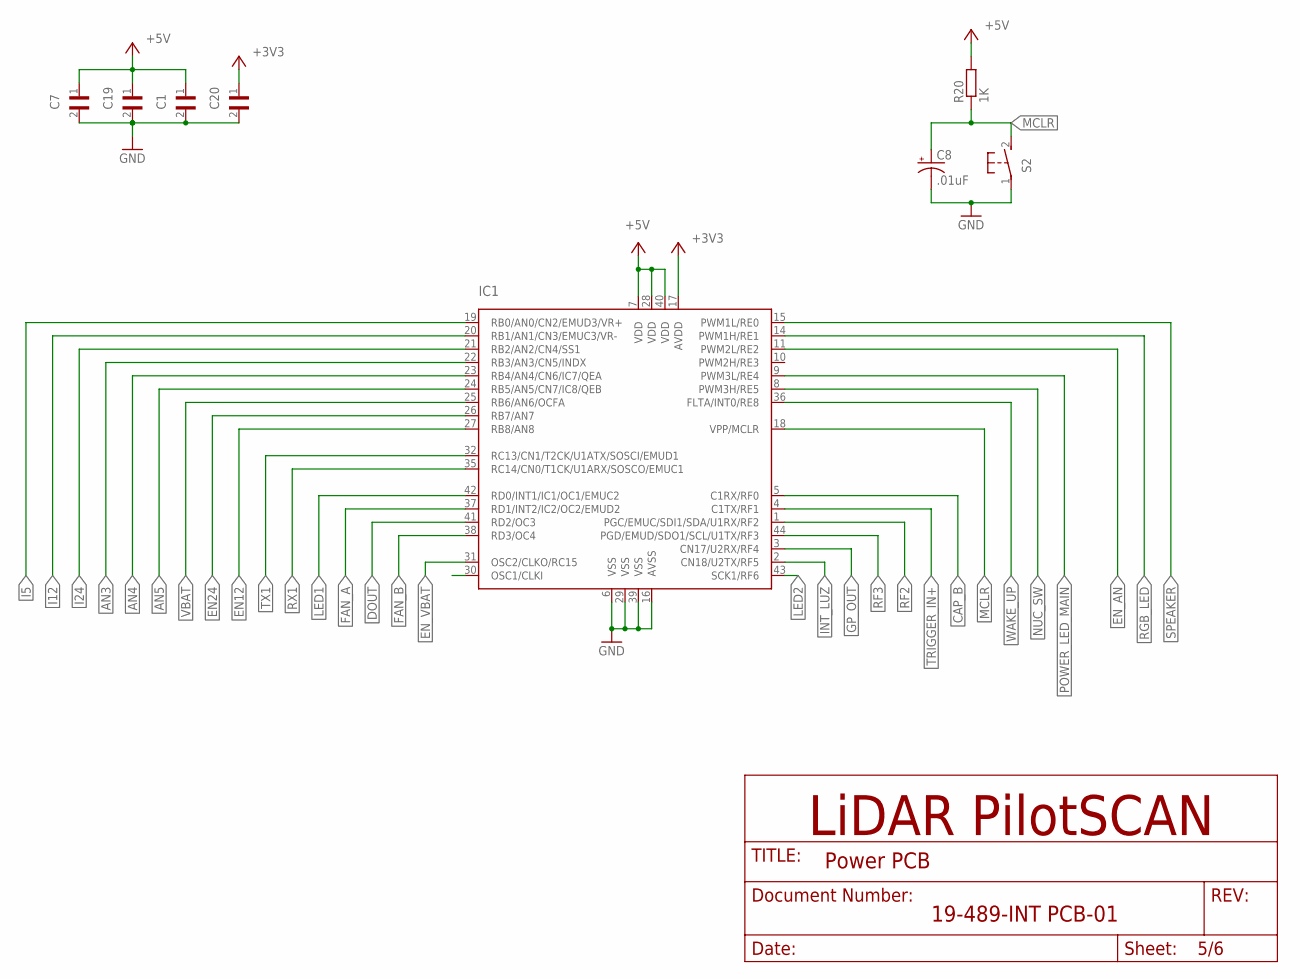
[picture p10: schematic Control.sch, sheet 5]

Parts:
C1, C7, C19, C20: 08056C104JAZ2A; CAPC2012X140N
C8: .01uF; CL03A104KQ3NNNC
IC1: DSPIC30F4011/PT; TQFP44
R20: 1K; RMCF0805FT1K00
S2: DTSM-3

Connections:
+3V3: C20.1, IC1.17 (AVDD); also elsewhere on the board
+5V: C1.1, C7.1, C19.1, IC1.7 (VDD), IC1.28 (VDD), IC1.40 (VDD), R20.2; also elsewhere on the board
AN3: IC1.22 (RB3/AN3/CN5/INDX); also elsewhere on the board
AN4: IC1.23 (RB4/AN4/CN6/IC7/QEA); also elsewhere on the board
AN5: IC1.24 (RB5/AN5/CN7/IC8/QEB); also elsewhere on the board
CAP_B: IC1.5 (C1RX/RF0); also elsewhere on the board
DOUT: IC1.41 (RD2/OC3); also elsewhere on the board
EN12: IC1.27 (RB8/AN8); also elsewhere on the board
EN_AN: IC1.11 (PWM2L/RE2); also elsewhere on the board
EN_VBAT: IC1.31 (OSC2/CLKO/RC15); also elsewhere on the board
FAN_A: IC1.37 (RD1/INT2/IC2/OC2/EMUD2); also elsewhere on the board
FAN_B: IC1.38 (RD3/OC4); also elsewhere on the board
GND: C1.2, C7.2, C8.2 (-), C19.2, C20.2, IC1.6 (VSS), IC1.16 (AVSS), IC1.29 (VSS), IC1.39 (VSS), S2.1; also elsewhere on the board
GP_OUT: IC1.3 (CN17/U2RX/RF4); also elsewhere on the board
I5: IC1.19 (RB0/AN0/CN2/EMUD3/VR+); also elsewhere on the board
I12: IC1.20 (RB1/AN1/CN3/EMUC3/VR-); also elsewhere on the board
I24: IC1.21 (RB2/AN2/CN4/SS1); also elsewhere on the board
INT_LUZ: IC1.2 (CN18/U2TX/RF5); also elsewhere on the board
LED1: IC1.42 (RD0/INT1/IC1/OC1/EMUC2); also elsewhere on the board
LED2: IC1.43 (SCK1/RF6); also elsewhere on the board
MCLR: C8.1 (+), IC1.18 (VPP/MCLR), R20.1, S2.2; also elsewhere on the board
NUC_SW: IC1.8 (PWM3H/RE5); also elsewhere on the board
POWER_LED_MAIN: IC1.9 (PWM3L/RE4); also elsewhere on the board
RF2: IC1.1 (PGC/EMUC/SDI1/SDA/U1RX/RF2); also elsewhere on the board
RF3: IC1.44 (PGD/EMUD/SDO1/SCL/U1TX/RF3); also elsewhere on the board
RGB_LED: IC1.14 (PWM1H/RE1); also elsewhere on the board
RX1: IC1.35 (RC14/CN0/T1CK/U1ARX/SOSCO/EMUC1); also elsewhere on the board
SPEAKER: IC1.15 (PWM1L/RE0); also elsewhere on the board
TRIGGER_IN+: IC1.4 (C1TX/RF1); also elsewhere on the board
TX1: IC1.32 (RC13/CN1/T2CK/U1ATX/SOSCI/EMUD1); also elsewhere on the board
VBAT: IC1.25 (RB6/AN6/OCFA); also elsewhere on the board
WAKE_UP: IC1.36 (FLTA/INT0/RE8); also elsewhere on the board

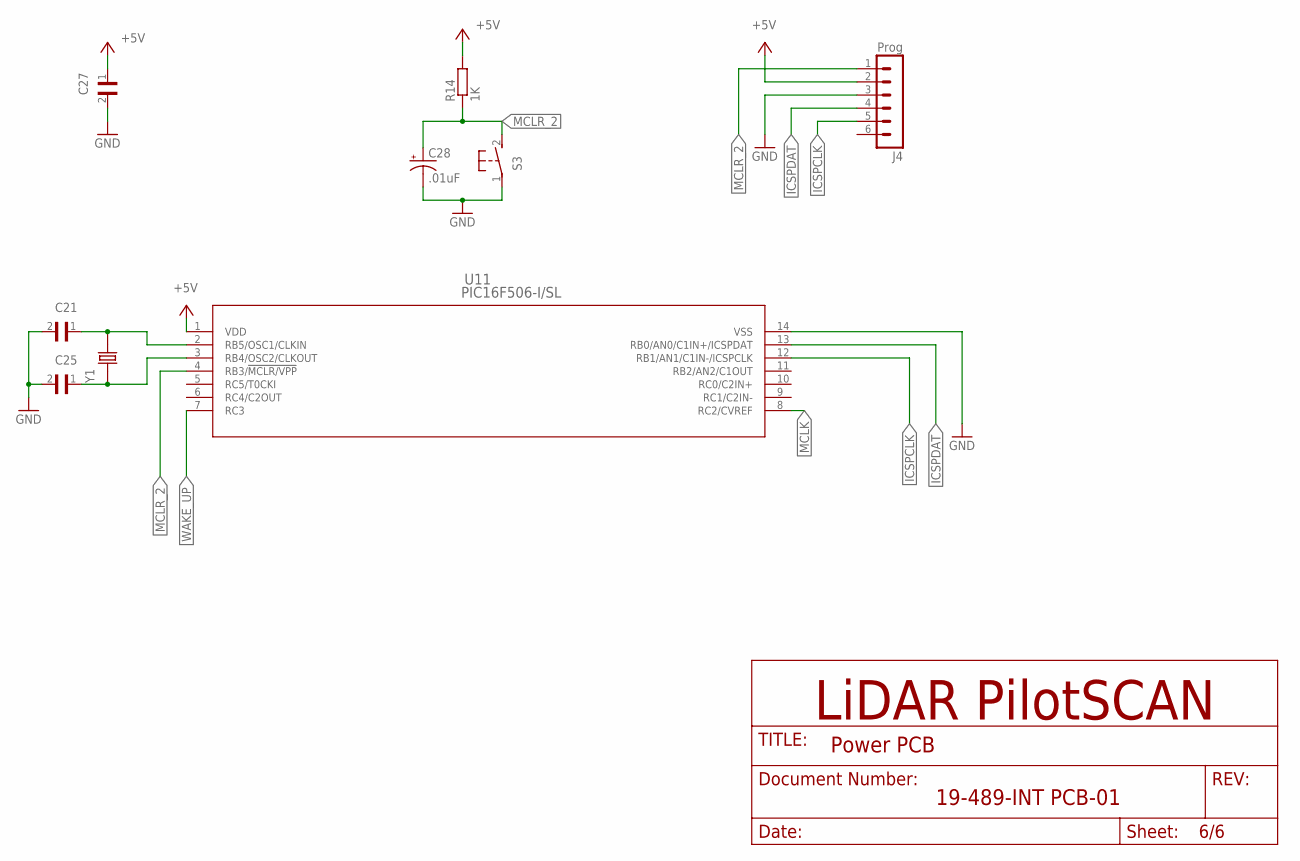
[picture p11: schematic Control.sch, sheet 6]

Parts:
C21, C25: C0603C150M8GACTU; CAPC1608X90
C27: 08056C104JAZ2A; CAPC2012X140N
C28: .01uF; CL03A104KQ3NNNC
J4: Prog; MA06-1
R14: 1K; RMCF0805FT1K00
S3: DTSM-3
U11: PIC16F506-I/SL; SOIC14-N_MC
Y1: ECS-10-13-1XH; XTAL_ECS-10-13-1XH

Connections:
+5V: C27.1, J4.2, R14.2, U11.1 (VDD); also elsewhere on the board
GND: C21.2, C25.2, C27.2, C28.2 (-), J4.3, S3.1, U11.14 (VSS); also elsewhere on the board
ICSPCLK: J4.5, U11.12 (RB1/AN1/C1IN-/ICSPCLK)
ICSPDAT: J4.4, U11.13 (RB0/AN0/C1IN+/ICSPDAT)
LVP: J4.6
MCLK: U11.8 (RC2/CVREF); also elsewhere on the board
MCLR_2: C28.1 (+), J4.1, R14.1, S3.2, U11.4 (RB3/!MCLR/VPP)
unnamed: C21.1, U11.2 (RB5/OSC1/CLKIN), Y1.2
unnamed: C25.1, U11.3 (RB4/OSC2/CLKOUT), Y1.1
WAKE_UP: U11.7 (RC3); also elsewhere on the board

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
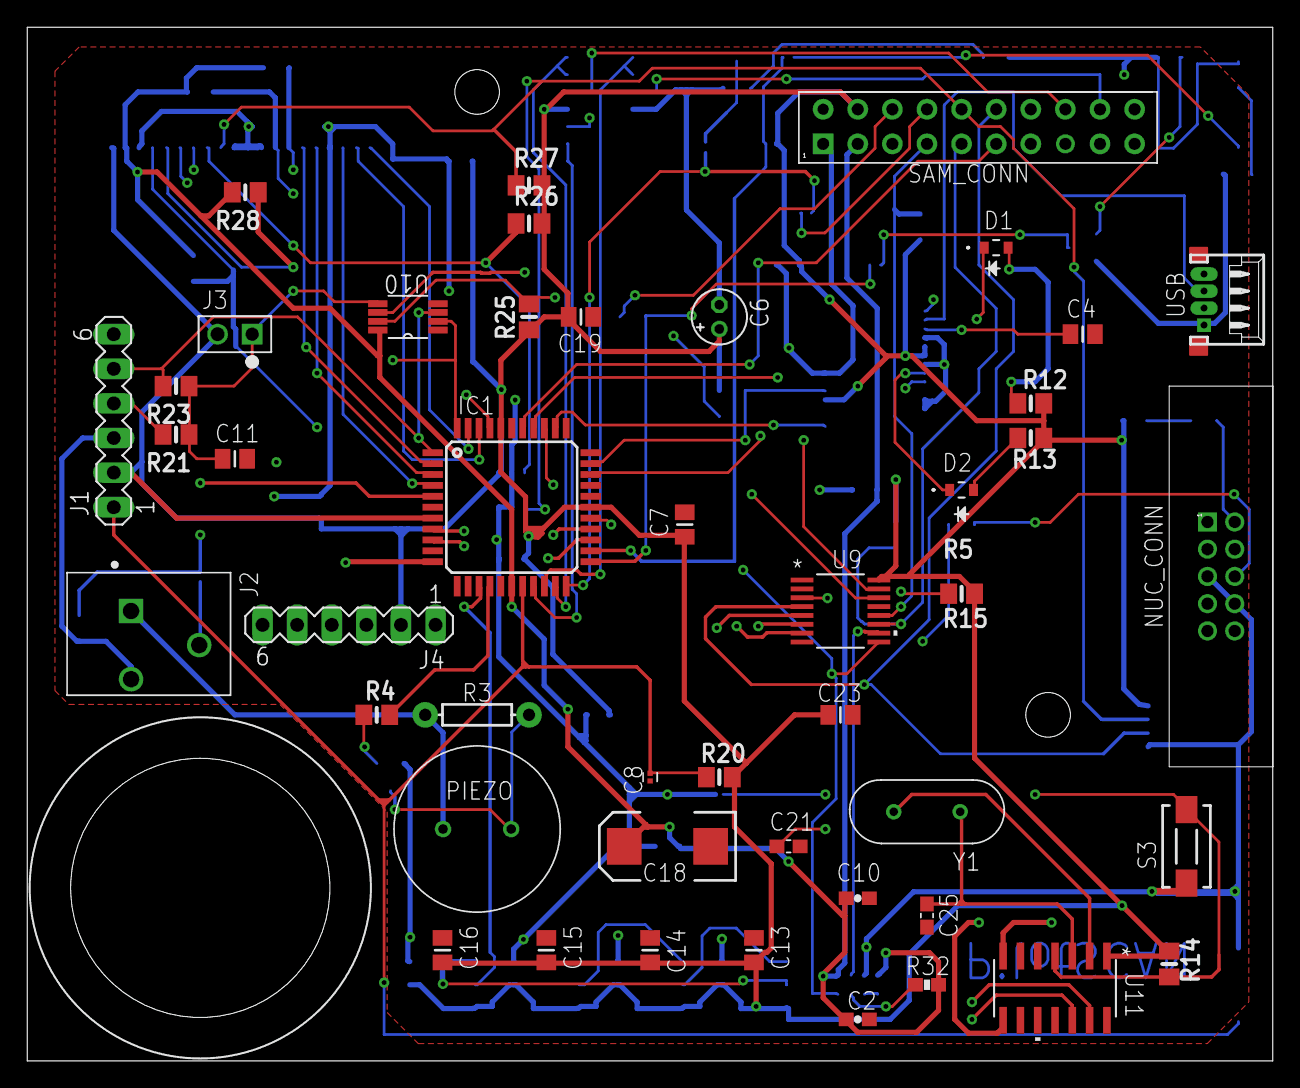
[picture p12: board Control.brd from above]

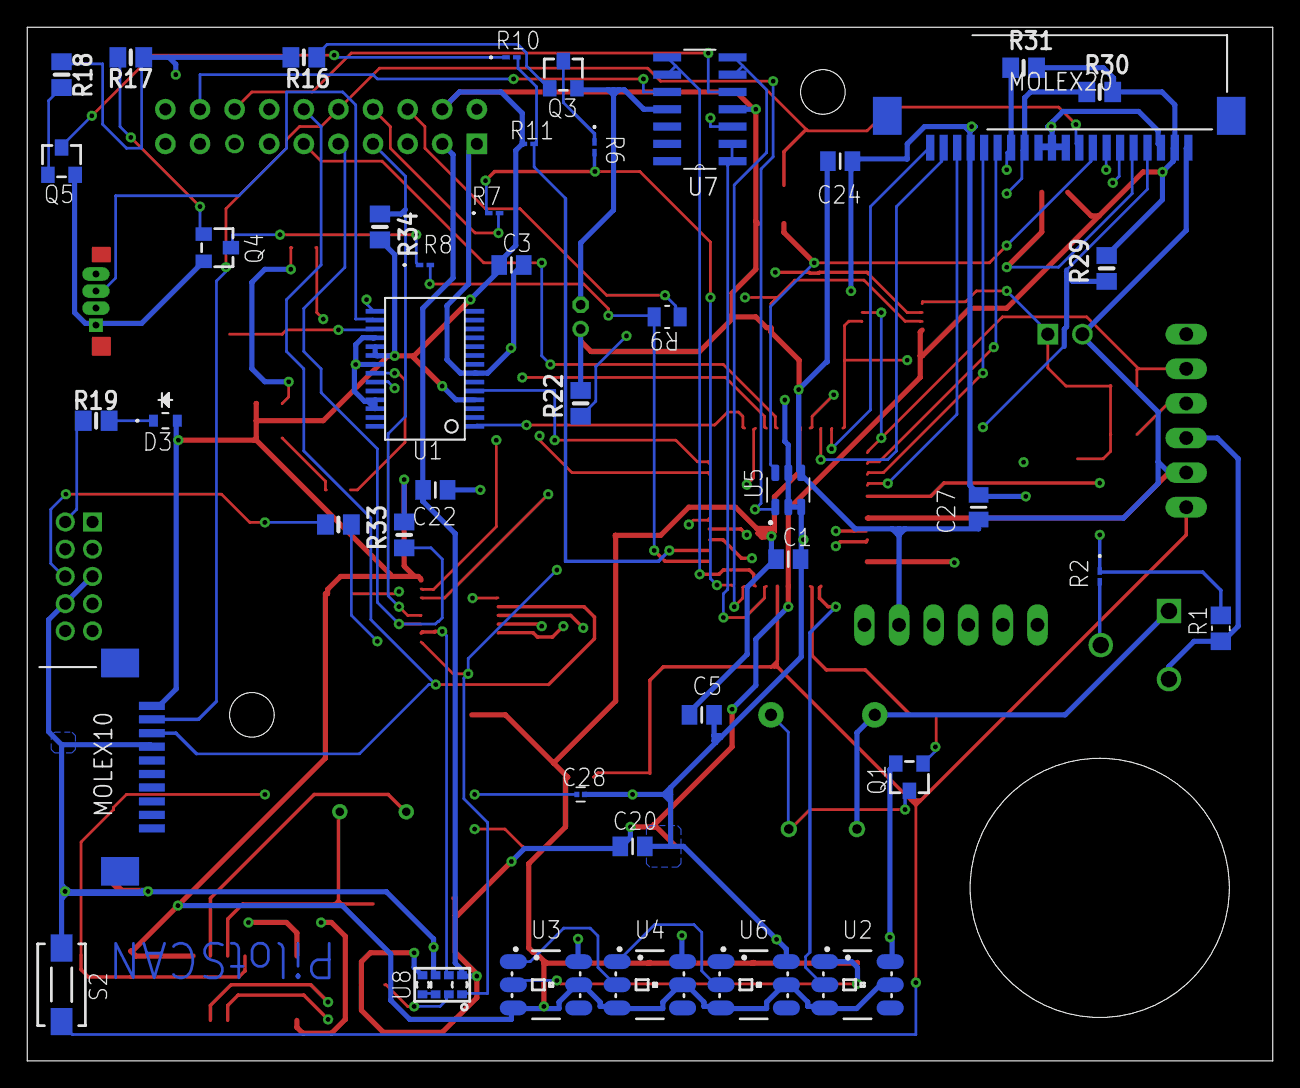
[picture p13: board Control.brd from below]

Board: 4 copper layers, 91.4 x 75.9 mm, 89 parts (43 on the bottom side), 79 nets.

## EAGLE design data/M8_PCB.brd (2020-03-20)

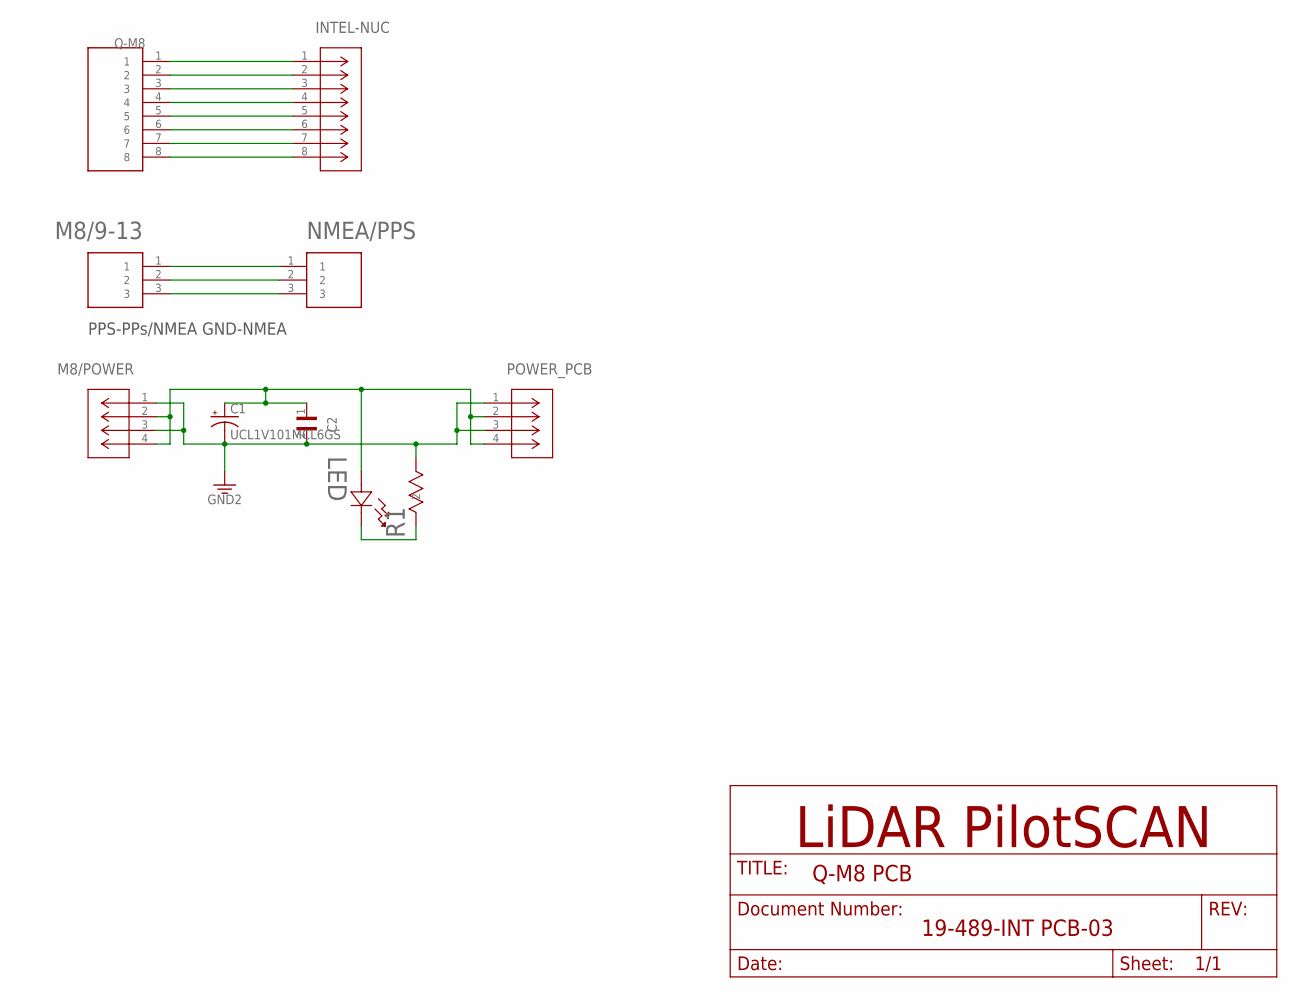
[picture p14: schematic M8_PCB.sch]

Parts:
C1: UCL1V101MCL6GS; U2-K
C2: GRM033R6YA104KE14D; CAPC0603X33N
INTEL-NUC: LLC; 0955032881
LED: VLMC3100-GS08; LED_PLCC_VSMB
M8/9-13: 1-2834021-3; CONN_1-2834021-3
M8/POWER: 3-794630-4; CON4_2X2_P3MM_VMNL2
NMEA/PPS: 1-2834021-3; CONN_1-2834021-3
POWER_PCB: 3-794630-4; CON4_2X2_P3MM_VMNL2
Q-M8: 292133-8; TE_292133-8
R1: CRCW04026K80FKEDHP; RES_CRCW_0402

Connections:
GROUND: C1.2 (-), C2.2, M8/POWER.1, M8/POWER.3, POWER_PCB.1, POWER_PCB.3, R1.1
unnamed: INTEL-NUC.1, Q-M8.1
unnamed: INTEL-NUC.2, Q-M8.2
unnamed: INTEL-NUC.3, Q-M8.3
unnamed: INTEL-NUC.4, Q-M8.4
unnamed: INTEL-NUC.5, Q-M8.5
unnamed: INTEL-NUC.6, Q-M8.6
unnamed: INTEL-NUC.7, Q-M8.7
unnamed: INTEL-NUC.8, Q-M8.8
unnamed: M8/9-13.1, NMEA/PPS.1
unnamed: M8/9-13.2, NMEA/PPS.2
unnamed: M8/9-13.3, NMEA/PPS.3
unnamed: LED.1, R1.2
POWER+: C1.1 (+), C2.1, LED.2, M8/POWER.2, M8/POWER.4, POWER_PCB.2, POWER_PCB.4

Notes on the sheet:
PPS-PPs/NMEA GND-NMEA

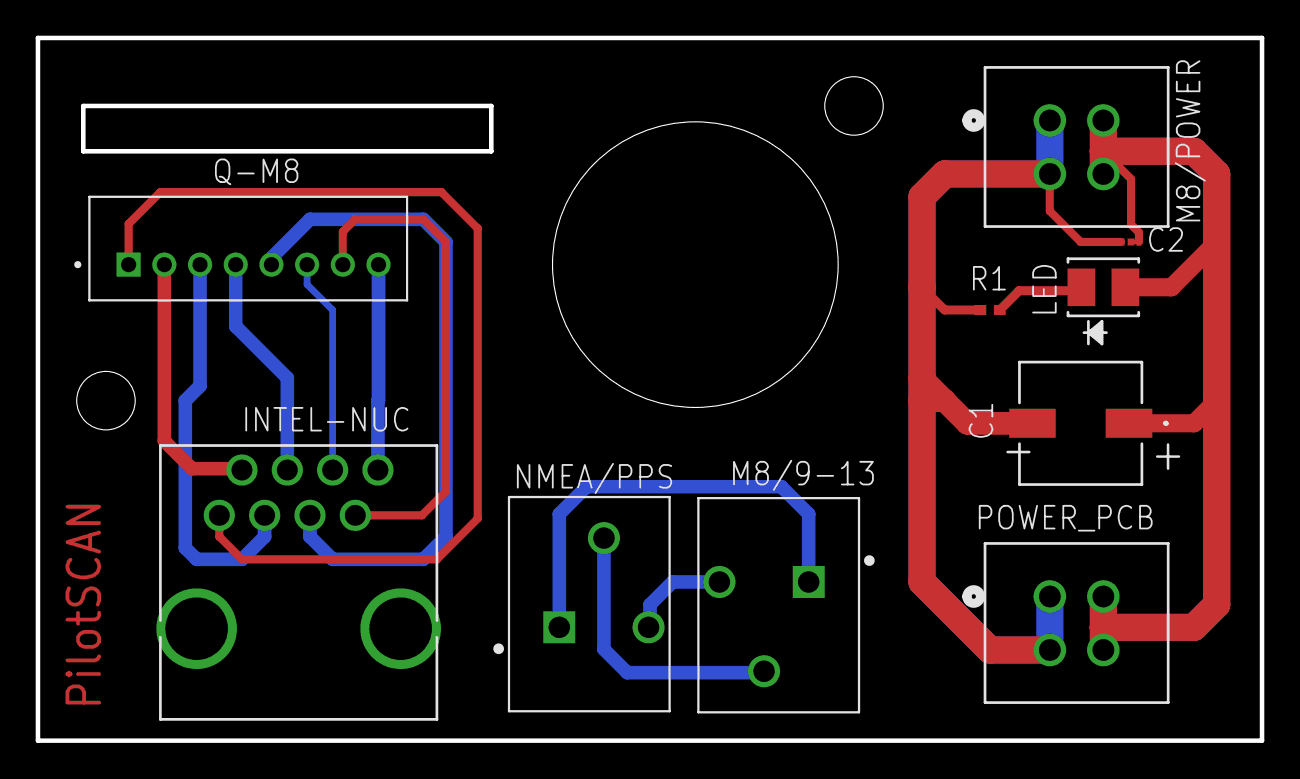
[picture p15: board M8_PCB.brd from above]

Board: 2 copper layers, 68.6 x 39.4 mm, 10 parts (0 on the bottom side), 14 nets.

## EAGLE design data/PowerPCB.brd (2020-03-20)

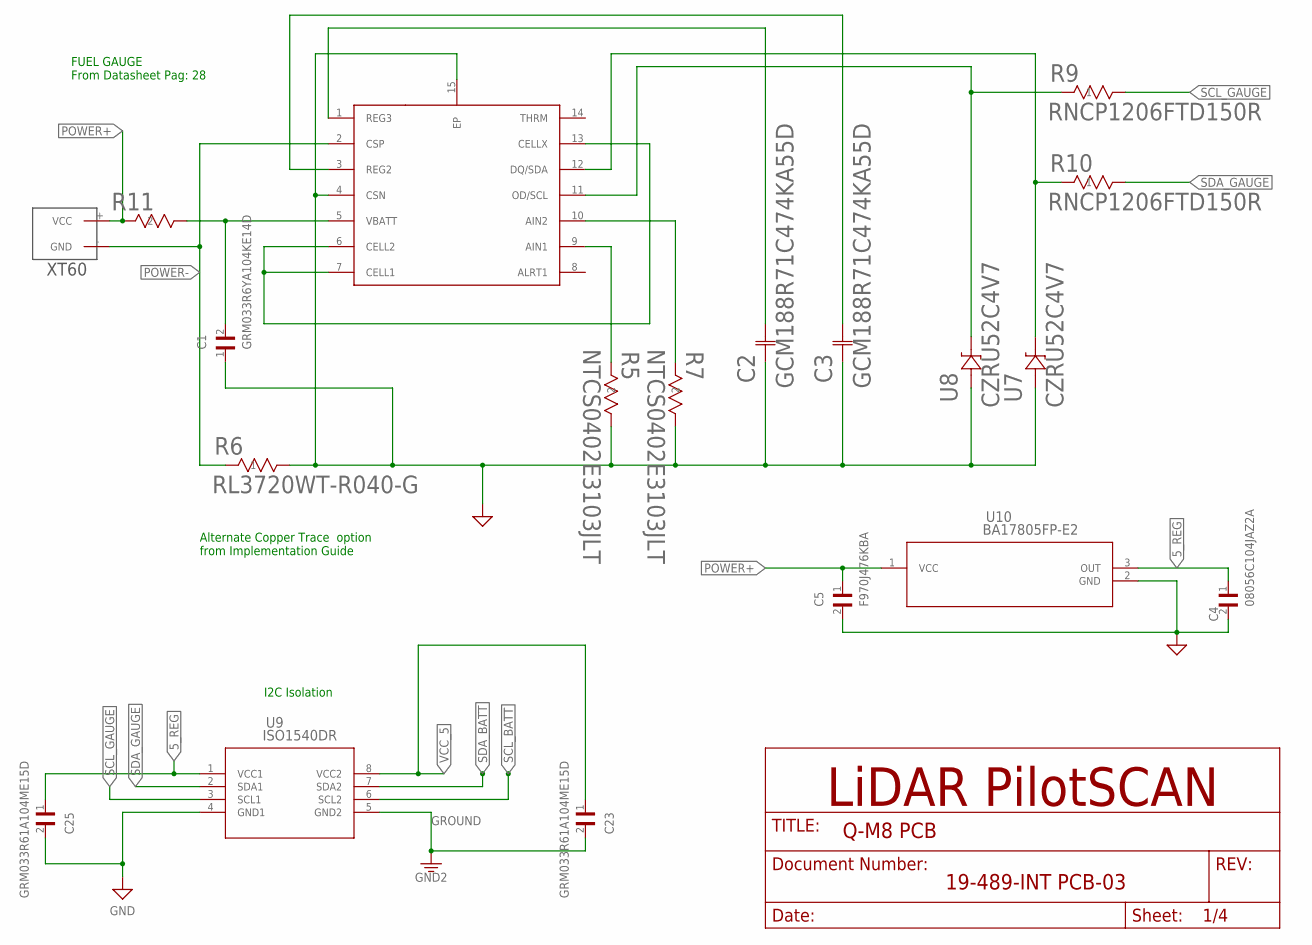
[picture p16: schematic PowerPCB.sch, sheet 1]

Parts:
C1: GRM033R6YA104KE14D; CAPC0603X33N
C2, C3: GCM188R71C474KA55D; G-188
C4: 08056C104JAZ2A; CAPC2012X140N
C5: F970J476KBA; CAPPC3528X210N
C23, C25: GRM033R61A104ME15D; CAPC0603X33N
J5: XT60
R5, R7: NTCS0402E3103JLT; RES_0402_NTC
R6: RL3720WT-R040-G; RES_2037
R9, R10: RNCP1206FTD150R; STA_RNCP1206
R11: ERA-2AKD100X; RC0402N
U5: MAX17205G+T
U7, U8: CZRU52C4V7; CZRU
U9: ISO1540DR; D8
U10: BA17805FP-E2; TO252-3

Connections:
5_REG: C4.1, C25.1, U9.1 (VCC1), U10.3 (OUT); also elsewhere on the board
GND: C1.1, C2.1, C3.1, C4.2, C5.2, C25.2, R5.1, R6.2, R7.1, U5.4 (CSN), U5.15 (EP), U7.2, U8.2, U9.4 (GND1), U10.2 (GND); also elsewhere on the board
GROUND: C23.2, U9.5 (GND2); also elsewhere on the board
unnamed: C1.2, R11.1, U5.5 (VBATT)
unnamed: R5.2, U5.9 (AIN1)
unnamed: C2.2, U5.1 (REG3)
unnamed: R7.2, U5.10 (AIN2)
unnamed: C3.2, U5.3 (REG2)
unnamed: U5.6 (CELL2), U5.7 (CELL1), U5.13 (CELLX)
unnamed: R9.1, U5.11 (OD/SCL), U8.1
unnamed: R10.1, U5.12 (DQ/SDA), U7.1
POWER+: C5.1, J5.+ (VCC), R11.2, U10.1 (VCC); also elsewhere on the board
POWER-: J5.- (GND), R6.1, U5.2 (CSP)
SCL_BATT: U9.6 (SCL2); also elsewhere on the board
SCL_GAUGE: R9.2, U9.3 (SCL1)
SDA_BATT: U9.7 (SDA2); also elsewhere on the board
SDA_GAUGE: R10.2, U9.2 (SDA1)
VCC_5: C23.1, U9.8 (VCC2); also elsewhere on the board

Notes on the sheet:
FUEL GAUGE From Datasheet Pag: 28
I2C Isolation
Alternate Copper Trace option from Implementation Guide

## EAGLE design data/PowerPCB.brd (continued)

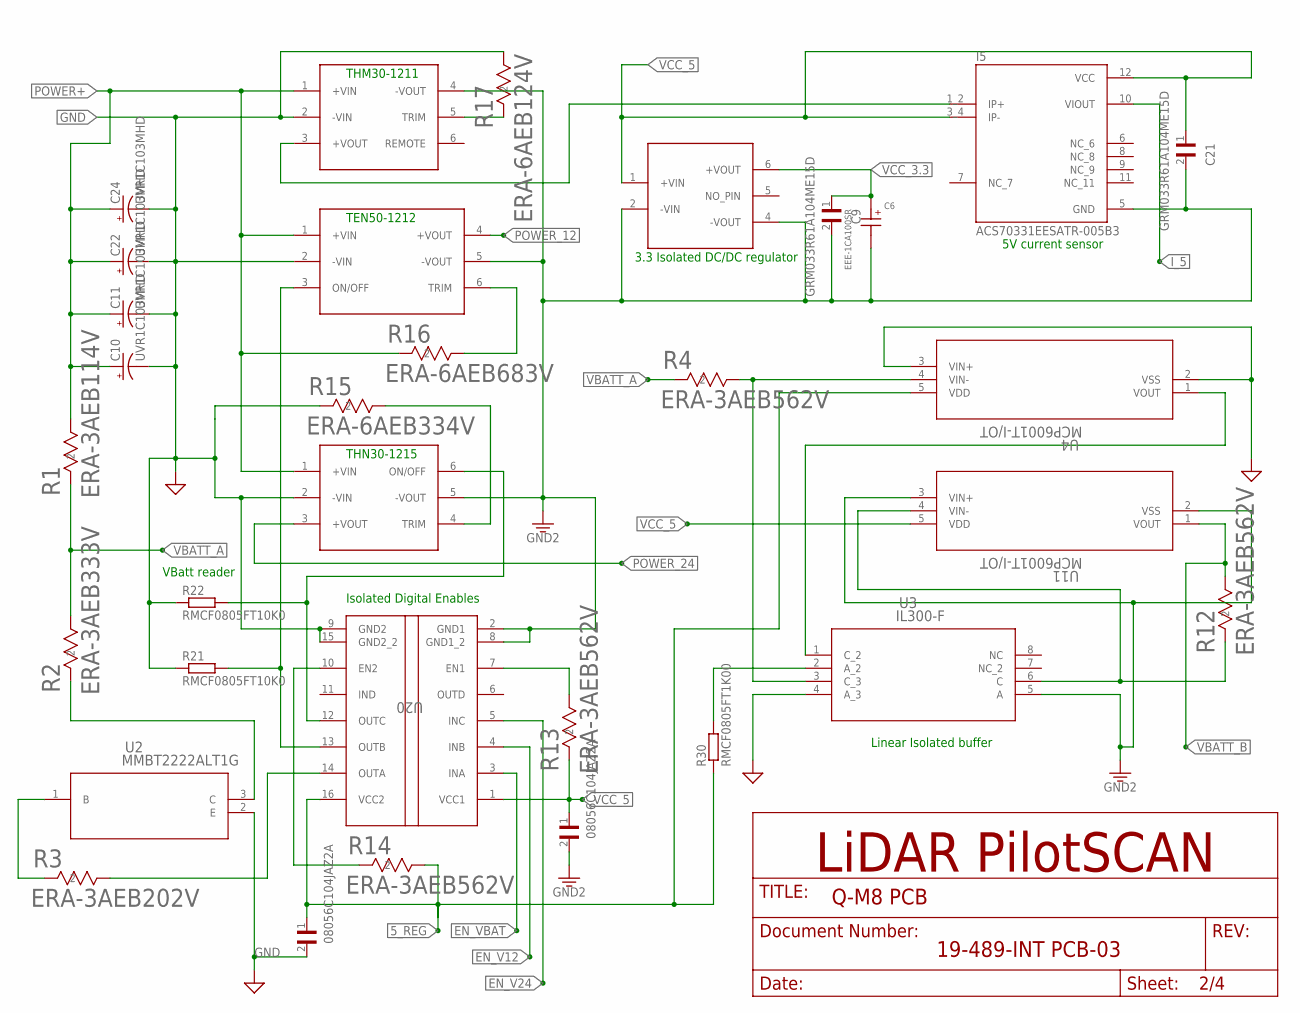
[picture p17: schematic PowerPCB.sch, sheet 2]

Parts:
C6: EEE-1CA100SR; CAPAE430X550N
C7, C8: 08056C104JAZ2A; CAPC2012X140N
C9, C21: GRM033R61A104ME15D; CAPC0603X33N
C10, C11, C22, C24: UVR1C103MHD; U1-PP
DCDC5: THM30-1211
DCDC12: TEN50-1212
DCDC24: THN30-1215
I5: ACS70331EESATR-005B3; ACS70331EESATR-2P5U3
R1: ERA-3AEB114V; RC0603N
R2: ERA-3AEB333V; RC0603N
R3: ERA-3AEB202V; RC0603N
R4, R12, R13, R14: ERA-3AEB562V; RC0603N
R15: ERA-6AEB334V; RC0805N
R16: ERA-6AEB683V; RC0805N
R17: ERA-6AEB124V; RC0805N
R21, R22: RMCF0805FT10K0
R30: RMCF0805FT1K00
U2: MMBT2222ALT1G; SOT-23
U3: IL300-F; DIP8_IL
U4, U11: MCP6001T-I/OT; SOT-23-5_MC
U6: TMV0503SHI
U20: ISO7741DBQR; DBQ0016A_N

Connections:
5_REG: C8.1, R14.1, R30.1, U4.5 (VDD), U20.16 (VCC2); also elsewhere on the board
EN_V12: U20.4 (INB); also elsewhere on the board
EN_V24: U20.5 (INC); also elsewhere on the board
EN_VBAT: U20.3 (INA); also elsewhere on the board
GND: C8.2, C10.2 (-), C11.2 (-), C22.2 (-), C24.2 (-), DCDC5.2 (-VIN), DCDC12.2 (-VIN), DCDC24.2 (-VIN), R15.2, R17.1, R21.1, R22.1, U2.2 (E), U3.4 (A_3), U4.2 (VSS), U4.3 (VIN+), U20.9 (GND2), U20.15 (GND2_2); also elsewhere on the board
GROUND: C6.2, C7.2, C9.2, C21.2, DCDC5.4 (-VOUT), DCDC12.5 (-VOUT), DCDC24.5 (-VOUT), I5.5 (GND), U3.5 (A), U6.2 (-VIN), U6.4 (-VOUT), U11.2 (VSS), U11.3 (VIN+), U20.2 (GND1), U20.8 (GND1_2); also elsewhere on the board
I_5: I5.10 (VIOUT); also elsewhere on the board
unnamed: R13.1, U20.7 (EN1)
unnamed: R3.2, U2.1 (B)
unnamed: R2.2, U2.3 (C)
unnamed: R4.1, U3.3 (C_3), U4.4 (VIN-)
unnamed: DCDC12.3 (ON/OFF), R21.2, U20.13 (OUTB)
unnamed: R30.2, U3.2 (A_2)
unnamed: R14.2, U20.10 (EN2)
unnamed: U3.1 (C_2), U4.1 (VOUT)
unnamed: R12.2, U3.6 (C), U11.4 (VIN-)
unnamed: DCDC24.6 (ON/OFF), R22.2, U20.12 (OUTC)
unnamed: R3.1, U20.14 (OUTA)
unnamed: DCDC5.5 (TRIM), R17.2
unnamed: DCDC24.4 (TRIM), R15.1
unnamed: DCDC12.6 (TRIM), R16.1
POWER+: C10.1 (+), C11.1 (+), C22.1 (+), C24.1 (+), DCDC5.1 (+VIN), DCDC12.1 (+VIN), DCDC24.1 (+VIN), R1.1, R16.2; also elsewhere on the board
POWER_5: DCDC5.3 (+VOUT), I5.1_2 (IP+)
POWER_12: DCDC12.4 (+VOUT); also elsewhere on the board
POWER_24: DCDC24.3 (+VOUT); also elsewhere on the board
VBATT_A: R1.2, R2.1, R4.2
VBATT_B: R12.1, U11.1 (VOUT); also elsewhere on the board
VCC_3.3: C6.1, C9.1, U6.6 (+VOUT); also elsewhere on the board
VCC_5: C7.1, C21.1, I5.3_4 (IP-), I5.12 (VCC), R13.2, U6.1 (+VIN), U11.5 (VDD), U20.1 (VCC1); also elsewhere on the board

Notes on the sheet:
Isolated Digital Enables
Linear Isolated buffer
5V current sensor
3.3 Isolated DC/DC regulator
VBatt reader
THM30-1211
THN30-1215
TEN50-1212


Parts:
C12: UWX1A101MCL1GB; PCAP_6.3X5.4-ELECT
C13, C15: UCL1V101MCL6GS; U2-K
C14, C16: GRM033R6YA104KE14D; CAPC0603X33N
C17, C18, C19, C20: GRM033R61A104ME15D; CAPC0603X33N
FAN_A: 1-2834021-3; CONN_1-2834021-3
FAN_B: 1-2834021-3; CONN_1-2834021-3
I12, I24: ACS70331EESATR-005B3; ACS70331EESATR-2P5U3
INTEL/NUC: 3-794630-4; CON4_2X2_P3MM_VMNL2
J1, J2: 77311-118-02LF
Q-FAN_A: BCP5416TA; SOT-223
Q-FAN_B: BCP5416TA; SOT-223
Q/M8: 3-794630-4; CON4_2X2_P3MM_VMNL2
R19, R20: CRCW0402150RFKEDHP; RES_CRCW_0402
TMP_POWER: TMP100NA/3K
X1: IPT1-110-01-L-D

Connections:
EN_V12: X1.P$18; also elsewhere on the board
EN_V24: X1.P$16; also elsewhere on the board
EN_VBAT: X1.P$20; also elsewhere on the board
GROUND: C12.2, C13.2 (-), C14.2, C15.2 (-), C16.2, C17.2, C18.2, C19.1, C20.2, I12.5 (GND), I24.5 (GND), INTEL/NUC.2, INTEL/NUC.4, Q-FAN_A.3 (E), Q-FAN_B.3 (E), Q/M8.2, Q/M8.4, TMP_POWER.2 (GND), TMP_POWER.5 (ADD0), X1.P$1, X1.P$2, X1.P$13; also elsewhere on the board
I_5: X1.P$19; also elsewhere on the board
I_12: I12.10 (VIOUT), X1.P$17
I_24: I24.10 (VIOUT), X1.P$15
unnamed: J1.1 (A1), X1.P$5
unnamed: J2.1 (A1), X1.P$7
unnamed: FAN_A.2, Q-FAN_A.2 (C_2), Q-FAN_A.4 (C)
unnamed: R20.1, X1.P$12
unnamed: R19.1, X1.P$14
unnamed: Q-FAN_B.1 (B), R20.2
unnamed: Q-FAN_A.1 (B), R19.2
unnamed: FAN_B.2, Q-FAN_B.2 (C_2), Q-FAN_B.4 (C)
POWER_12: I12.1_2 (IP+); also elsewhere on the board
POWER_24: I24.1_2 (IP+); also elsewhere on the board
SCL_BATT: X1.P$8; also elsewhere on the board
SCL_TEMP: TMP_POWER.1 (SCL), X1.P$9
SDA_BATT: X1.P$10; also elsewhere on the board
SDA_TEMP: TMP_POWER.6 (SDA), X1.P$11
VBATT_B: X1.P$6; also elsewhere on the board
VCC_3.3: X1.P$4; also elsewhere on the board
VCC_5: C12.1, C17.1, C18.1, C19.2, C20.1, I12.12 (VCC), I24.12 (VCC), TMP_POWER.3 (ADD1), TMP_POWER.4 (V+), X1.P$3; also elsewhere on the board
VCC_12: C15.1 (+), C16.1, I12.3_4 (IP-), INTEL/NUC.1, INTEL/NUC.3, J1.2 (A2); also elsewhere on the board
VCC_24: C13.1 (+), C14.1, FAN_A.1, FAN_A.3, FAN_B.1, FAN_B.3, I24.3_4 (IP-), J2.2 (A2), Q/M8.1, Q/M8.3; also elsewhere on the board


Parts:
+5V, +12V, +24V: 1-2834021-3; CONN_1-2834021-3

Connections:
GROUND: +5V.1, +12V.1, +24V.1; also elsewhere on the board
VCC_5: +5V.2, +5V.3; also elsewhere on the board
VCC_12: +12V.2, +12V.3; also elsewhere on the board
VCC_24: +24V.2, +24V.3; also elsewhere on the board



Board: 4 copper layers, 151.3 x 90.0 mm, 77 parts (33 on the bottom side), 56 nets.

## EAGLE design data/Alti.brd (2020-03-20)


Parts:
C1, C2: 47uF; CL31A476MQHNNWE
C5: 0.1uF; CAPC2012X140N
D1, D2: TLMS1000-GS08; RESC1608X55
J1: 1-2834021-3; CONN_1-2834021-3
R1: 30; 1812X7R
R2: 4.7k; RMCF0805FT4K70
R3, R4: RC0201JR-071K8L; RES_RC0201_P6XP3
U1: XF3M(1)-2015-1B
U2: 325540009-50
U3: SI1147-M01-GM
U5: TMP100NA/3K

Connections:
+3V3: C1.2 (+), C2.2 (+), R1.2, R2.1, U1.19, U2.P$5 (VDD), U3.P$4 (VDD), U3.P$6 (LED2), U3.P$7 (LED3)
+5V: C5.1, U1.20, U5.4 (V+), U5.5 (ADD0)
DOUT: U1.15, U2.P$8 (DOUT)
GND: C1.1 (-), C2.1 (-), C5.2, D1.2 (C), D2.2 (C), J1.2, U1.4, U1.9, U1.10, U1.11, U1.18, U2.P$2 (GND), U3.P$8 (GND), U5.2 (GND), U5.3 (ADD1)
GP_OUT: J1.3, U1.5
INT_LUZ: R2.2, U1.6, U3.P$5 (INT)
LED1: R3.2, U1.2
LED2: R4.2, U1.1
MCLK: U1.14, U2.P$6 (MCLK)
unnamed: D1.1 (A), R3.1
unnamed: D2.1 (A), R4.1
unnamed: R1.1, U3.P$10 (LEDA)
SCL0: U1.12, U5.1 (SCL)
SCL1: U1.17, U2.P$1 (SCLK)
SCL2: U1.7, U3.P$3 (SCL)
SDA0: U1.13, U5.6 (SDA)
SDA1: U1.16, U2.P$7 (DIN)
SDA2: U1.8, U3.P$2 (SDA)
TRIGGER_IN+: J1.1, U1.3

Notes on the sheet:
alt luz leds temp cam
External Temperature sensor addr: 0x4A



Board: 2 copper layers, 88.5 x 35.6 mm, 14 parts (12 on the bottom side), 19 nets.

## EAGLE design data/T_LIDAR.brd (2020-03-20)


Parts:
C5: .1uF; CAPC2012X140N
TMP_LIDAR: 522071060
U5: TMP100NA/3K

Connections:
+5V: C5.1, TMP_LIDAR.10, U5.3 (ADD1), U5.4 (V+), U5.5 (ADD0)
GND: C5.2, TMP_LIDAR.7, U5.2 (GND)
SCL0: TMP_LIDAR.9, U5.1 (SCL)
SDA0: TMP_LIDAR.8, U5.6 (SDA)

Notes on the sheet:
DSPic Temperature sensor addr: 0x4E


Board: 2 copper layers, 60.9 x 61.0 mm, 3 parts (1 on the bottom side), 4 nets.

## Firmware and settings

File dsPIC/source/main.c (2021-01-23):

#include <xc.h>
//#device ADC=12
#define OSC_INTERNAL
//#use delay (clock = 120000000)
//#fuses FRC_PLL16,NOPROTECT,NOWDT,NOPUT,MCLR

//#use RS232(BAUD=9600,BITS=8,PARITY=N,XMIT=PIN_C13,RCV=PIN_C14,TIMEOUT=10)// UART
//#use i2c(Master,sda=PIN_F2,scl=PIN_F3)// I2C

/********************************************/
// Import Libraies
/********************************************/
#include "ports.h"
#include <Include\NOTAS.c>
#include <Include\TONOS.c>
#include <Include\serialProtocol.h>
#include <Include\NUC_interface.h>
#include <Include\I2C_dir.h>

/********************************************/
// Global Variables
/********************************************/

int1 aux_binary = 1;
int1 flag_info = 0;
int1 shut_down = 0;
int cont_tm4 = 0;
char cont_tm5 = 0;
int16 I5, I12, I24, m24V, m12V, m05V, mVbat;
char buffer[6];



const float S2I = 1.25*3.0/4095.0;	// Sensor of current
const float S24 = 11.99*3.0/4095.0;	// Sensor of 24 V
const float S12 = 6.19*3.0/4095.0;	// Sensor of 12 V
const float S05 = 2.35*3.0/4095.0;	// Sensor of 05 V
const float Sbat = 4.33*3.0/4095.0;	// Sensor of batery voltage

/********************************************/
// General configuration
/********************************************/

void ADC_setup(){
	setup_adc_ports(sAN0 | sAN1 | sAN2 | sAN3 | sAN4 | sAN5 | sAN6);
	setup_adc(ADC_CLOCK_INTERNAL);
}

void INT_setup(){
	ENABLE_INTERRUPTS(INTR_GLOBAL);
	EXT_INT_EDGE(L_TO_H);
	CLEAR_INTERRUPT(INT_EXT0);
	CLEAR_INTERRUPT(INT_RDA);
}
/********************************************/
// General Functions
/********************************************/

void linea2(){
	generate_tone(NOTA_MI[2],negra);
}

int16 Read_ADC_ports(int ch){
	SET_ADC_CHANNEL(ch);
	delay_us(10);
	return READ_ADC();
}
// Declaration of time constans
// Practical estimation of timing waveforms
const int TH0 = 5;//0.3us
const int TH1 = 16;//0.6us
const int TL0 = 16;//0.9us
const int TL1 = 7;//0.6us

// Color  chage  Detection
void RBG(int R,int  G,int B){
	int i;
	// Green value
	for(i = 0;i<8;i++){
		output_high(LED_RGB);
		if ((G>>7)&0x01){
			delay_cycles(TH1);
			output_low(LED_RGB);
			delay_cycles(TL1);
		}
		else{
			delay_cycles(TH0);
			output_low(LED_RGB);
			delay_cycles(TL0);
		}
		G<<=1;
	}
	// Red value
	for(i = 0;i<8;i++){
		output_high(LED_RGB);
		if ((R>>7)&0x01){
			delay_cycles(TH1);
			output_low(LED_RGB);
			delay_cycles(TL1);
		}
		else{
			delay_cycles(TH0);
			output_low(LED_RGB);
			delay_cycles(TL0);
		}
		R<<=1;
	}
	// Blue value
	for(i = 0;i<8;i++){
		output_high(LED_RGB);
		if ((B>>7)&0x01){
			delay_cycles(TH1);
			output_low(LED_RGB);
			delay_cycles(TL1);
		}
		else{
			delay_cycles(TH0);
			output_low(LED_RGB);
			delay_cycles(TL0);
		}
		B<<=1;
	}
}

void send_serial(long data){
	printf ("$%ld\n",data);
}

/********************************************/
// Interruptions
/********************************************/
#int_EXT0
void  EXT0_isr(void){
	CLEAR_INTERRUPT(int_EXT0);
	aux_binary = !aux_binary;
//	OUTPUT_BIT(LED1,aux_binary);
}

#int_RDA
void RDA_isr(void){
	disable_interrupts(int_rda);
    unsigned int i = 0;
    char inp;
    inp = getc();
    //putc(inp);
    while(inp != '\n'){
        buffer[i] = inp;
        inp = getc();
        //putc(inp);
        i++;
    }
    int n = sizeof(buffer);
    Hex2data(buffer,n);
	ENABLE_INTERRUPTS(int_rda);
}

#int_TIMER4
void  TIMER4_isr(void){
	disable_interrupts(INT_TIMER4);
	if (cont_tm4==50){
		if (INPUT(Cap_bot)){
			enable_interrupts(INT_TIMER4);
			//generate_tone(NOTA_si[2],corchea);
			output_high(EN_ANA);
			output_high(EN_VBAT);

			//time_off = 0;
//			if (INPUT(NUC_LED)){
//				sw_NUC(); 			// Turn on NUC
//				delay_ms(120000);
//			}else{
//				/********************************************/
//				// Main Program
//				/********************************************/
//				H_actions(0x04, 0x0d);
				H_actions(NUC_state[0],NUC_state[1]);

				send_serial(data2Hex(I5*S2I, 0x01));
				send_serial(data2Hex(I12*S2I, 0x02));
				send_serial(data2Hex(I24*S2I, 0x03));
				send_serial(data2Hex(m05V*S05, 0x05));
				send_serial(data2Hex(m12V*S12, 0x06));
				send_serial(data2Hex(m24V*S24, 0x07));
				send_serial(data2Hex(mVbat*Sbat, 0x08));

				shut_down = 0;
				output_low(EN_ANA);
				output_low(EN_VBAT);
				flag_info = 1;

				RBG(R1,G1,B1);
				RBG(R2,G2,B2);
				RBG(R3,G3,B3);
				RBG(R4,G4,B4);
//			}
		}else{
			if (!shut_down){
				Ending1();
				output_low(EN_VBAT);
				shutdown_NUC();
				output_low(EN12);
				output_low(EN24);
				output_low(EN_ANA);
				shut_down = 1;
			}
		}
		cont_tm4 = 0;
	}
	else{
		cont_tm4++;
	}
	set_timer4(0);
	enable_interrupts(INT_TIMER4);
}

#int_TIMER5
void  TIMER5_isr(void){
	if (cont_tm5 < cycles){
		output_high(FAN_A);
		output_high(FAN_B);
	}
	else{
		output_low(FAN_A);
		output_low(FAN_B);
	}
	cont_tm5 ++;
	if (cont_tm5 == 10)
		cont_tm5 = 0;
}

/********************************************/
// Main Function
/********************************************/
void main(){
	setup();
	output_low(EN12);
	output_low(EN24);
	output_low(EN_ANA);
	output_high(NUC_ON_OFF);
	ADC_setup();
	INT_setup();
	setup_timer4(TMR_INTERNAL |TMR_DIV_BY_256 ,1550);
	setup_timer5(TMR_INTERNAL |TMR_DIV_BY_8 ,453);

	delay_ms(300);


//	int data_in = 0;
//	int n = 0;
	delay_ms(500);
	output_high(EN12);
	output_high(EN24);
	delay_ms(500);
	INPUT(Cap_bot);


	/***************************************/
	//			L2 L3 L4 L1 button
	/***************************************/
	int cont_RGB = 0;
	R1 = 0; G1 = 250; B1 = 0; R2 = 0; G2 = 250; B2 = 0;
	R3 = 0; G3 = 250; B3 = 0; R4 = 0; G4 = 250; B4 = 0;
	do{
		if (cont_RGB < 250){
			RBG(0,0,0);
			RBG(255,128,0);
			RBG(0,0,0);
			RBG(0,0,0);
		}else if(cont_RGB < 500){
			RBG(0,0,0);
			RBG(0,250,0);
			RBG(255,128,0);
			RBG(0,0,0);
		}else if(cont_RGB < 750){
			RBG(0,0,0);
			RBG(0,250,0);
			RBG(0,250,0);
			RBG(255,128,0);
		}else{
			RBG(255,128,0);
			RBG(0,250,0);
			RBG(0,250,0);
			RBG(0,250,0);
		}
		delay_ms(1);
		cont_RGB++;
	}while(cont_RGB<2000);
	RBG(R1,G1,B1);
	RBG(R2,G2,B2);
	RBG(R3,G3,B3);
	RBG(R4,G4,B4);

	opening1();

	ENABLE_INTERRUPTS(INT_EXT0);
	ENABLE_INTERRUPTS(INT_RDA);
	ENABLE_INTERRUPTS(INT_TIMER4);
	ENABLE_INTERRUPTS(INT_TIMER5);

	while(TRUE){
		output_high(NUC_ON_OFF);

		// Current medition
		I5 = Read_ADC_ports(CH_I5);
		I12 = Read_ADC_ports(CH_I12);
		I24 = Read_ADC_ports(CH_I24);

		// Voltage medition
		m24V = Read_ADC_ports(CH_24V);
		m12V = Read_ADC_ports(CH_12V);
		m05V = Read_ADC_ports(CH_05V);
		mVbat = Read_ADC_ports(CH_VBAT);

		// restar variables
		f_error = 0;
		f_conn = 1;
		f_conSta = 0;
		f_begin = 0;
		RAM_error = 0;
		HDD_error = 0;
		if(flag_info = 1){
			action();
		}
		flag_info = 0;
	}
}

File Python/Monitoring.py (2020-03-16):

import rospy
from diagnostic_msgs.msg import KeyValue
from diagnostic_msgs.msg import DiagnosticArray
from sensor_msgs.msg import Temperature
from std_msgs.msg import String
from sensor_msgs.msg import BatteryState

cont_v = 0.0
cont_I = 0.0
pub_1 = rospy.Publisher('firmware/PowerSource/virtual/Batt_05', BatteryState, queue_size=10)
pub_2 = rospy.Publisher('firmware/PowerSource/virtual/Batt_12', BatteryState, queue_size=10)
pub_3 = rospy.Publisher('firmware/PowerSource/virtual/Batt_24', BatteryState, queue_size=10)
pub_4 = rospy.Publisher('firmware/PowerSource/Battery', BatteryState, queue_size=10)
msg_1 = BatteryState()
msg_2 = BatteryState()
msg_3 = BatteryState()
msg_4 = BatteryState()


def int2hex(num):
    switcher = {
        0:          '0',
        1:          '1',
        2:          '2',
        3:          '3',
        4:          '4',
        5:          '5',
        6:          '6',
        7:          '7',
        8:          '8',
        9:          '9',
        10:         'a',
        11:         'b',
        12:         'c',
        13:         'd',
        14:         'e',
        15:         'f'
    }
    data_hex = switcher.get(num, '0')
    return data_hex

def command_deco(num):
    switcher = {
        0:          '0',
        1:          'I_5',
        2:          'I_12',
        3:          'I_24',
        4:          'I_Batt',
        5:          'V_5',
        6:          'V_12',
        7:          'V_24',
        8:          'V_Batt',
        9:          'T_',
        10:         'T_',
        11:         'T_',
        12:         'T_',
        13:         'H',
        14:         'e',
        15:         'f'
    }
    data = switcher.get(num, '0')
    return data

def Hex2data(message):
    if message[0]=='$':
        # print message
        message2 = message.split('$')
        try:
            data_doc = int(message2[1])
            msg_1.header.stamp = rospy.Time.now()
            msg_2.header.stamp = rospy.Time.now()
            msg_3.header.stamp = rospy.Time.now()
            msg_4.header.stamp = rospy.Time.now()
            command =   0x00F & (data_doc>>16);
            data1 =     0x00F & (data_doc>>12);
            data2 =     0x00F & (data_doc>>8);
            checksum =  0x0FF & (data_doc);
            data1_hex =     int2hex(data1)
            data2_hex =     int2hex(data2)
            # print (command,data1,data2,checksum)
            if command<9:
                if (command+data1+data2)!=checksum:
                    if (command+data1+data2+5)==checksum:
                        data_str = data1_hex+data2_hex
                        data = float(data_str,16)
                    else:
                        data = 0
                else:
                    data_h = int(data1_hex,16)
                    data_l = int(data2_hex,16)
                    data_str = str(data_h)+'.'+str(data_l)
                    data = float(data_str)
                # print data_str
                # print data
                type_value = command_deco(command)
                # print type_value
                if type_value == 'V_5':
                    msg_1.voltage = data
                elif type_value == 'V_12':
                    msg_2.voltage = data
                elif type_value == 'V_24':
                    msg_3.voltage = data
                elif type_value == 'V_Batt':
                    msg_4.voltage = data
                elif type_value == 'I_5':
                    msg_1.current = data
                elif type_value == 'I_12':
                    msg_2.current = data
                elif type_value == 'I_24':
                    msg_3.current = data
                elif type_value == 'I_Batt':
                    msg_4.current = data
                elif type_value == 'T_':
                    print 'hola'
                elif type_value == 'H':
                    print 'hola'
                # print type_value+' = '+str(data)
                pub_1.publish(msg_1)
                pub_2.publish(msg_2)
                pub_3.publish(msg_3)
                pub_4.publish(msg_4)

        except:
            pass

def data2Hex(message):
    pub = rospy.Publisher('Serial_out', String, queue_size=10)
    message2 = message.split('-')
    switcher1 = {
	"sys":	    '0',
	"memo":	    'a',
        "vn300":    '1',
        "M8":       '2',
        "cam":      '3',
	"fuzz":	    '4'
    }
    switcher2 = {
	"on_24":	'1',
	"off_12":	'2',
	"0ff_24":	'3',
	"RAM_E1":	'1',
	"RAM_E2":	'2',
	"ROM_E1":	'6',
	"ROM_E2":	'7',
	"ROM_E3":	'8',
        "NC":       '1',
        "start":    '2',
        "<25":      '3',
        "<50":      '4',
        "<75":      '5',
        ">75":      '6',
        "work":     '7',
	"T1":	'c',
	"T2":	'd',
	"T3":	'e',
	"T4":	'f'
    }
    dato1 = switcher1.get(message2[0], "0")
    dato2 = switcher2.get(message2[1], "0")
    checksum_int = int(dato1,16)+int(dato2,16)
    checksum1 = int2hex(checksum_int/16)
    checksum2 = int2hex(checksum_int%16)
    string = dato1+dato2+checksum1+checksum2
    info = int(string,16)
    serial_message = str(info)
#    print serial_message
    pub.publish(serial_message)
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

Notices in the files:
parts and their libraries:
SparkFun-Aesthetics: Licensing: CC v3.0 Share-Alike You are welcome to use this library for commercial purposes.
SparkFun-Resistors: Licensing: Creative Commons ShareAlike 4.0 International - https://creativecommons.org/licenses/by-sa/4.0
